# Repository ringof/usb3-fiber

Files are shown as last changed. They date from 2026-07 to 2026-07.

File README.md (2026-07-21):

# USB3-over-Fiber Link

USB3 SuperSpeed carried over an optical fiber link, using a **DS100BR111**
redriver into a **10GbE SR SFP+** optical module. A single symmetric PCB serves
both ends of the link — host-side and remote-side roles are selected by jumpers.
The **MCP2221A** provides the SFP+ management (I²C) interface and GPIO for
`TX_DISABLE` / `RX_LOS`. **No microcontroller, no firmware, no EEPROM.**

Built as the remote front-end for an SDR receiver: put the ADC at the antenna
and stream USB3 back to the shack over fiber.

## How it works

```
USB3-A connector        ┌───────────────┐        SFP+ cage
(SuperSpeed pairs) ─────►│  DS100BR111   │◄─────► (optical module) ──► fiber
                        │ (pin-strapped, │
                        │   3.3V)        │
                         └───────────────┘
                                │ SDA/SCL
                          ┌───────────┐
                          │ MCP2221A  │── USB micro-B ── laptop (SFP+ mgmt)
                          └───────────┘
```

Each fiber link needs **two identical boards** — one at the antenna, one at the
shack — with jumpers `JP1`/`JP2` selecting the role. The USB3 path is fully
symmetric: the DS100BR111 is bidirectional and the SFP+ module handles both TX
and RX in one cage.

## Central hypothesis

This prototype exists to test one thing:

> A 10GbE SR SFP+ optical module will transport USB3 SuperSpeed signalling
> intact — LFPS bursts, link training, electrical-idle transitions,
> spread-spectrum clocking, and receiver detection — without modifying the
> module or the USB3 endpoints.

It has been done in the amateur-radio and USB-extension communities, but it is
guaranteed by no specification. See
[`docs/USB3_Fiber_Link_Minimal_Circuit.md`](docs/USB3_Fiber_Link_Minimal_Circuit.md)
for the architecture, channel assignment, and the failure modes this board is
built to probe.

## Repository layout

| Path | Contents |
|---|---|
| `usb3_fiber.kicad_pro/.kicad_sch/.kicad_pcb` | The design. |
| `usb3_fiber.kicad_dru` | Custom high-speed design rules (length/skew/coupling/isolation/via-count). |
| `fp-lib-table` / `sym-lib-table` | Project-local library tables (`${KIPRJMOD}`). |
| `library/` | Symbols (`usb3_fiber.kicad_sym`), footprints (`.pretty/`), 3D models (`3dmodels/`). |
| `datasheets/` | Component datasheets. |
| `docs/` | Design intent, fab spec, turnkey/CI pipeline, release strategy, and the repo migration plan. |

## Requirements

- **KiCad 10.0** (latest stable 10.0.4) — the project baseline.

## Building the manufacturing outputs

From the repo root, with `kicad-cli` (KiCad 10):

```sh
kicad-cli sch erc   usb3_fiber.kicad_sch --output erc.rpt
kicad-cli pcb drc   usb3_fiber.kicad_pcb --output drc.rpt   # honors .kicad_dru
kicad-cli sch export pdf     usb3_fiber.kicad_sch --output schematic.pdf
kicad-cli sch export bom     usb3_fiber.kicad_sch --output bom.csv
kicad-cli pcb export gerbers usb3_fiber.kicad_pcb --output gerbers/
kicad-cli pcb export drill   usb3_fiber.kicad_pcb --output gerbers/
kicad-cli pcb export pos     usb3_fiber.kicad_pcb --output cpl.csv
kicad-cli pcb export step    usb3_fiber.kicad_pcb --output usb3_fiber.step
```

## Fabrication

4-layer FR4, ENIG, controlled impedance (100 Ω differential on the high-speed
pairs), targeting **JLCPCB's standard 4-layer process**. Full stackup,
impedance, and drill/feature constraints are in
[`docs/fab_specification.txt`](docs/fab_specification.txt).

## Downloads

Latest release (see [all releases](../../releases)):

- 📄 **[Schematic (PDF)](https://github.com/ringof/usb3-fiber/releases/latest/download/usb3_fiber-schematic.pdf)**
- 🧩 **[Assembly drawing (PDF)](https://github.com/ringof/usb3-fiber/releases/latest/download/usb3_fiber-assembly.pdf)** — top + bottom component placement
- 📐 **[Fabrication drawing (PDF)](https://github.com/ringof/usb3-fiber/releases/latest/download/usb3_fiber-fabrication-drawing.pdf)** — overview/spec, per-layer, and drill maps
- 🛠 **[Gerbers — JLCPCB-ready (zip)](https://github.com/ringof/usb3-fiber/releases/latest/download/usb3_fiber-gerbers.zip)**
- 📦 **[Full fabrication + design package (zip)](https://github.com/ringof/usb3-fiber/releases/latest/download/usb3_fiber-fabrication.zip)** — Gerbers, drill, BOM, CPL, schematic PDF, assembly + fabrication drawings, STEP

Packages are built and version-stamped by CI. Versioning is semantic
(`vMAJOR.MINOR`): `dev` publishes `v0.x` pre-releases, and promotion to `main`
cuts production releases (`v1.0`, then `v2.0`, …). The version and git hash are
stamped into the title block and bottom silkscreen at build time, and named in
each release's title/tag. The download links above resolve to the newest
**production** release; during the pre-1.0 phase (only `v0.x` pre-releases so
far), grab the assets from the specific pre-release on the
[Releases page](../../releases). See
[`docs/RELEASE_STRATEGY.md`](docs/RELEASE_STRATEGY.md) for how versions and
releases work (a new version is cut only when the design changes).

## Status

Prototype. This is an unproven design intended to validate the central
hypothesis above. The current revision is whatever the latest
[release](../../releases) is — it's stamped into the board, not hardcoded here.

## License

[CERN-OHL-P v2](LICENSE) (CERN Open Hardware Licence Version 2 – Permissive,
SPDX `CERN-OHL-P-2.0`).

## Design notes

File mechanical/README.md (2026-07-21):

# Mechanical — enclosure & PCB end plates

The mechanical package for the USB3-over-Fiber link: the enclosure model and the
end-plate boards. It lives in **this repo, not a separate one** — see below.

> **Status: scaffold.** This README fixes the convention. Drop the enclosure STEP
> and the end-plate KiCad projects in here as they are created.

## Layout

```
mechanical/
  enclosure.step          # the case model — the EE↔ME interface artifact
  endplate-*/             # standalone KiCad projects, one per panel
```

Each end plate is its **own** self-contained KiCad project (its own
`fp-lib-table` / `sym-lib-table`); the root `usb3_fiber` board is untouched. The
end plates are **non-functional PCBs** — Edge.Cuts, connector cutouts, mounting
holes, and silkscreen (labels + logos) — fabricated in place of the blank panels
a stock enclosure ships with.

Because the board is symmetric — one design serves both the antenna-side and
shack-side ends of the link — a single set of end plates fits both units.

## Why in this repo, not a separate one

The end plates are **mechanically coupled** to the main board: their cutouts have
to track the board's connector positions — the USB3-A connector (`J3`/`J4`), the
SFP+ cage opening (`J1`), and the USB micro-B management port. Keeping them here
means a connector move and its matching cutout move land as **one atomic,
reviewed commit**, and they version and travel together. A separate repo would
split that into two places to keep in sync by hand — exactly the drift we're
avoiding.

## Versioning — deliberately separate from the board

A change under `mechanical/` **does not cut a board release.** The `dev-release`
/ `main-release` version lanes are scoped to the **root board's** files only —
they list `usb3_fiber.kicad_{sch,pcb,pro,dru}`, `library/`, and the lib-tables
explicitly rather than globbing `*.kicad_pcb` (which, as a git pathspec, would
match `mechanical/**` at any depth and false-trigger a board release). So an
end-plate silkscreen tweak never bumps the board's `vX.Y`. That scoping is
already in place — see #38.

The end plates are simple; build their fab outputs **on demand** for now, e.g.:

```sh
kicad-cli pcb export gerbers mechanical/endplate-front/endplate-front.kicad_pcb -o mechanical/endplate-front/gerbers/
kicad-cli pcb export drill   mechanical/endplate-front/endplate-front.kicad_pcb -o mechanical/endplate-front/gerbers/
```

A dedicated end-plate CI lane is a possible later addition, not a requirement.

## The board STEP is the interface

Mechanical design works from the board's exported **STEP** — board outline,
thickness, connector positions, component heights, and mounting holes.
`scripts/build_release.sh` already exports `usb3_fiber.step` (bundled inside the
`usb3_fiber-fabrication.zip` release asset). Publishing it as a **standalone
release asset** — so the case design can always pull the current board without
unzipping the fab package — is a small follow-up on the release jobs, and ties
into the 3D-model-completeness work. Until then, grab the STEP from inside the
latest release's fabrication zip, or regenerate it with:

```sh
kicad-cli pcb export step usb3_fiber.kicad_pcb -o usb3_fiber.step
```

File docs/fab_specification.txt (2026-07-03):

USB3 FIBER LINK - PCB FABRICATION SPECIFICATION
================================================

1. GENERAL REQUIREMENTS
   Board Name:         USB3 Fiber Link
   Layers:             4 (TOP / GND / PWR / BOTTOM)
   Material:           FR4, Standard Tg (150-160C)
   Finished Thickness: 62 mil (1.575mm) +/- 10%
   Surface Finish:     ENIG (1u" min gold thickness)
   Solder Mask:        Green, both sides (LPI)
   Silkscreen:         White, both sides
   IPC Class:          2 (Standard)
   UL Marking:         Not required

2. STACKUP
   Layer          Type       Thickness    Copper Weight
   -----          ----       ---------    -------------
   F.Cu           Signal     0.035mm      1 oz
   Prepreg        7628       0.21mm       Er=4.5, Df=0.02
   In1.Cu         GND Plane  0.0175mm     0.5 oz
   Core           FR4        1.03mm       Er=4.5, Df=0.02
   In2.Cu         PWR Plane  0.0175mm     0.5 oz
   Prepreg        7628       0.21mm       Er=4.5, Df=0.02
   B.Cu           Signal     0.035mm      1 oz

   Note: Exact prepreg/core thicknesses subject to fab stackup
   optimization for impedance targets below.

3. CONTROLLED IMPEDANCE
   Net Class       Type           Target     Tolerance
   ---------       ----           ------     ---------
   USB3_SS         Differential   100 ohm    +/- 10%
   USB3_SS         Single-ended   50 ohm     +/- 5 ohm
   SFP_SS          Differential   100 ohm    +/- 10%
   SFP_SS          Single-ended   50 ohm     +/- 5 ohm
   USB2            Differential   90 ohm     +/- 10%
   USB2            Single-ended   45 ohm     +/- 5 ohm

   Impedance-controlled traces are on F.Cu and B.Cu layers
   referenced to In1.Cu (GND) plane.

4. MINIMUM DESIGN FEATURES
   Parameter                    Value
   ---------                    -----
   Minimum track width          0.10mm (4 mil)
   Minimum track spacing        0.10mm (4 mil)
   Minimum via drill            0.30mm
   Minimum via pad diameter     0.50mm
   Minimum annular ring         0.10mm
   Minimum hole-to-hole         0.25mm
   Minimum copper-to-edge       0.50mm
   Minimum solder mask bridge   0.10mm (green, 1oz)
   Minimum mask-to-trace        0.09mm
   Minimum silkscreen width     0.153mm (6 mil)
   Minimum silkscreen height    1.0mm (40 mil)

5. DRILL REQUIREMENTS
   Plated through-hole tolerance:    +0.13 / -0.08mm
   Non-plated hole tolerance:        +/- 0.20mm
   Minimum plated slot width:        0.50mm
   Minimum non-plated slot width:    1.00mm
   No blind or buried vias required.

6. VIA TREATMENT
   All vias to be filled with soldermask (opaque finish).
   Filled vias must not have soldermask openings on either side.
   Maximum via diameter for plugging: 0.50mm.

7. DESIGN RULE CONSTRAINTS (enforced in layout)
   Net Class       Max Length   Diff Pair Skew   Track/Gap       Max Uncoupled
   ---------       ----------   --------------   ---------       -------------
   USB3_SS         25mm         0.1mm            0.2mm / 0.2mm   2mm
   SFP_SS          15mm         0.1mm            0.2mm / 0.2mm   2mm
   USB2            50mm         0.5mm            0.2mm / 0.15mm  5mm
   Power           --           --               0.5mm / 0.2mm   --
   Default         --           --               0.2mm / 0.2mm   --

   Additional high-speed constraints:
   - USB3 TX/RX pair-to-pair clearance:   0.5mm minimum
   - SFP TD/RD pair-to-pair clearance:    0.5mm minimum
   - USB3 to SFP inter-class clearance:   0.5mm minimum
   - USB3_SS max via count per net:        2
   - SFP_SS max via count per net:         2

8. NOTES
   a. All dimensions in millimeters unless otherwise noted.
   b. Panelization per fabricator requirements.
   c. Board outline defined in Edge.Cuts layer of Gerber files.
   d. Fiducials provided (4x, 1mm Cu with 2mm mask opening).
   e. Mounting holes: 4x M3 (3.2mm), non-plated.
   f. Fab to verify trace widths against actual stackup using
      impedance calculator and adjust if necessary.
   g. Target fabricator: JLCPCB (4-layer standard process).

9. DELIVERABLES REQUIRED FROM FABRICATOR
   a. Impedance test coupon results
   b. Cross-section report (if controlled impedance ordered)
   c. Final stackup confirmation before production

REVISION HISTORY
   Rev    Date          Description
   ---    ----------    -----------
   A      2026-03-13    Initial release

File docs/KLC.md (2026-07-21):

# KLC Compliance & Accepted Deviations

How this project relates to the **KiCad Library Convention (KLC)**, and the
places where we **intentionally deviate** from it.

KLC is checked in dev CI by `scripts/klc_check.sh` (kicad-library-utils over
`library/usb3_fiber.kicad_sym` and `library/usb3_fiber.pretty/`). It is
**warning-level only — it never gates a build** (see `docs/REPO_MIGRATION_PLAN.md`
Phase 5). The report is published to the `ci-docs` branch (`klc.txt`) and echoed
into the CI job summary.

The goal is **not** zero violations. KLC is written for the *official* KiCad
libraries; this is a **self-contained project library** with turnkey-assembly
requirements. A handful of KLC rules conflict with those requirements, and
"fixing" them would damage the design or the manufacturing pipeline. Those cases
are listed here as accepted deviations; everything else is remediated (tracked
in #36 and batch issues #32–#35).

## Accepted deviations

### 1. Custom BOM / part-spec fields — violates **S6.2** ("unexpected property")

Symbols carry non-standard fields that KLC flags as unexpected:

- `MANUFACTURER`, `Manufacturer Part Number` (MPN), `Vendor` / `Vendor Part
  Number` (LCSC), `PARTREV`
- Value-class attributes on the generic spec symbols: `Voltage`, `Tolerance`,
  `Temperature Coefficient`, `Impedance`, `DC Resistance`, `Max Current`, …

**Why kept:** these drive the **turnkey outputs** — the LCSC/JLCPCB BOM and the
rotation-corrected CPL read the `LCSC` / MPN / manufacturer fields (see
`usb3_fiber.kibot.yaml` and `docs/TURNKEY.md`). Deleting them to satisfy KLC
would break assembly ordering. **We keep them and accept the S6.2 flag.**

### 2. Project-local 3D-model layout — **F9.3 excluded** in the checker

Our 3D models are **committed to the repo** at `library/3dmodels/*.step` and
referenced as `${KIPRJMOD}/library/3dmodels/<model>.step`, so the library is
**self-contained** — models travel with the repo and resolve in CI with no
system-wide KiCad install.

KLC's **F9.3** is *structurally unsatisfiable* for this layout, by design of the
rule (verified in `rules_footprint/F9_3.py`): it only accepts the path prefix
`${KICAD10_3DMODEL_DIR}/` (the *global install* dir) and requires the model
directory to be exactly `<libname>.3dshapes`. With `${KIPRJMOD}` the prefix is
never stripped, so the directory check can never pass — conforming would mean
abandoning self-containment (installing models globally). It is therefore
**excluded** in `scripts/klc_check.sh` (`--exclude F9.3`). 3D-model *presence /
completeness* is covered separately by the planned 3D-completeness gate, so no
real coverage is lost.

(**F9.1** — footprint metadata — is *not* excluded: descriptions, keywords, and
datasheet URLs are filled in, and F9.1 is fully cleared. The unused
`QFP50P900X900X160-48N` footprint and the unused `USB2517I` part
(`QFN64_USB2517I` footprint + symbol + 3D model) were removed from the library.)

### 3. Generic value symbols have no datasheet — part of **S6.2**

`C_Spec`, `R_Spec`, `FB_Spec` are **generic value symbols** (a capacitor /
resistor / ferrite placeholder whose value is set per-instance), not specific
orderable parts, so they have no single datasheet. Leaving `Datasheet` empty on
these is intentional. **Accepted.** (Orderable parts do carry a datasheet.)

## What we DO remediate

Everything not listed above is fixed on the `dev-klc-compliance` branch, in
batches:

- **#32** — metadata & library linkage: footprint-filter formatting/escaping,
  missing/surplus filters, symbol keywords, footprint descriptions, and adding
  datasheets to orderable parts.
- **#33** — silkscreen, courtyard, and fabrication-layer graphics.
- **#34** — 3D-model requirements (path standardization per deviation 2, plus
  offset/rotation).
- **#35** — pin & pad conventions (per-part, against datasheets).

## Baseline

Post KiCad-10 library migration: **231 violations** (65 symbol + 166 footprint).
The accepted deviations above account for a portion that will remain in the
report by design; the remainder is the remediation target.

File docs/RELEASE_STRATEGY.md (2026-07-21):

# Release Strategy

How `usb3-fiber` versions the design, builds fabrication packages, and publishes
releases. Implemented by `.github/workflows/dev-release.yml` and
`main-release.yml` (with `dev-checks.yml` for pre-merge validation), sharing a
single versioning policy in `scripts/next_version.sh`.

## Branches & CI

Two-tier flow: **feature → `dev` → `main`**.

- **`dev-*`** feature branches are where work happens. They merge (squash) into
  **`dev`**, the permanent integration branch.
- **`dev`** collects vetted work. Each merge cuts a **pre-release** (see below).
  When the design is ready to spin, `dev` merges (squash) into **`main`**.
- **`main`** is the release branch. A merge here promotes the design to a
  **production revision**.
- Both `dev` and `main` are protected (PR required); `main` is the stricter
  release gate.

CI:

- **`dev-checks`** runs on `dev-*` pushes and on **PRs into `dev` and `main`**:
  ERC, DRC, BOM completeness, and schematic + assembly drawings as artifacts. So
  the same checks gate both feature→dev and dev→main.
- **`dev-release`** runs on every merge to `dev` and publishes/refreshes the
  **pre-release** for that iteration.
- **`main-release`** runs on every merge to `main` (and can be dispatched
  manually) and publishes **production revisions** and their packages.

## Versioning

Semantic `MAJOR.MINOR`. Think of it as **`main` = production board spins;
`dev` = the iterations toward the next spin.**

**`main` advances to the next whole `.0`; `dev` does the minor increments** in
between. `dev`'s major line simply follows whatever `main` last shipped.

| Event | Version |
|---|---|
| `dev` merge, pre-1.0 | `0.1 → 0.2 → 0.3 …` (minor++) |
| **first `dev → main`** | **`1.0`** |
| `dev` merge, post-1.0 | `1.1 → 1.2 → 1.3 …` (minor++ in the 1.x line) |
| **next `dev → main`** | **`2.0`** |
| `dev` merge, post-2.0 | `2.1 → 2.2 …` |
| **next `dev → main`** | **`3.0`** |

- **`main` release** = `<latest main major + 1>.0`; first-ever → `1.0`. Every
  production release is a whole major — no auto-minor, and no manual major
  decision needed. Published as a normal (non-prerelease) Release so it lands as
  "Latest".
- **`dev` pre-release** = minor increment within the **current major line**,
  whose major follows the latest `main` release (`0` while pre-1.0). The first
  `dev` pre-release after a `main` `X.0` starts at `X.1`; the very first
  pre-release while pre-1.0 uses the seed (`0.1`). Published with `--prerelease`
  so it never claims "Latest".

The "back it into dev" step is **automatic**: `dev-release` reads `main`'s latest
major through the shared script, so the first pre-release after `main` ships
`1.0` computes as `1.1` on its own — no manual back-merge of a version number.

**GitHub Releases are the source of truth** for the version — no number lives in
the design files. Tags are `v<MAJOR>.<MINOR>`; the title matches (pre-releases
add a ` (pre-release)` suffix). The policy is implemented **once** in
`scripts/next_version.sh` (unit-tested offline by `scripts/test_next_version.sh`)
and called by both lanes, so `dev` and `main` can't drift apart.

> **Legacy tags:** the earlier alpha releases (`revA`/`revB`/`revC`) predate this
> scheme. Both workflows scope their release scan to `v<MAJOR>.<MINOR>` tags, so
> those alpha tags are simply ignored by the version math.

### Pre-releases (dev lane)

`dev-release` runs on every merge to `dev` and publishes a `--prerelease`:

- Computes the next `dev` version via `scripts/next_version.sh dev 0.1` and
  publishes when a design file changed since the last release (of any kind);
  docs/CI/script-only merges are a no-op.
- **First run seeds the line** at `v0.1` from the design at `dev` HEAD —
  automated, no manual tag.
- **Does not retire at 1.0.** After `main` ships `1.0`, `dev` continues in the
  `1.x` line (`1.1`, `1.2`, …) building toward the next `main` (`2.0`); after
  `2.0` it runs `2.x`; and so on.

Both lanes accept the same manual `version` override / `dry_run` inputs.

## When is a new revision cut?

Each lane publishes **only when a design file changed** since its base release;
docs/CI/script-only merges are a **no-op** — they run the workflow, determine
nothing changed, and stop without building or publishing.

- **`dev-release`** compares against the **most recent release of any kind**.
- **`main-release`** compares against the **most recent production
  (non-prerelease) release** — a `dev` pre-release never gates a production spin.
  The **first** production release always publishes `v1.0` (it is the promotion
  of the current design to production, not a diff).

**Design files** (a change to any of these triggers an uprev):

- `usb3_fiber.kicad_sch`, `usb3_fiber.kicad_pcb`, `usb3_fiber.kicad_pro`,
  `usb3_fiber.kicad_dru`
- `library/**` (symbols, footprints, and STEP models), `fp-lib-table`,
  `sym-lib-table`

The root board files are listed **explicitly** in the workflows (not as
`*.kicad_*` globs, which as git pathspecs match at any depth and would let a
future sibling KiCad project under `mechanical/` false-trigger a board release).

**Not design files** (never trigger an uprev): `README.md`, `docs/**`,
`.github/**`, `scripts/**`, and `*.kicad_prl` (editor/UI state).

The comparison is made against **the last release's commit**, not just the
merge's own diff — so a design edit that landed in an earlier (unpublished)
commit is still caught, and a later docs-only merge cannot mask it.

## Provenance (`${REVISION}` and `${GIT_HASH}`)

Both are **injected at build time** (`scripts/inject_provenance.py`) into the
project text variables and rendered into the schematic/PCB **title block** and
the **bottom silkscreen**. Nothing is committed back to the design files — the
defaults committed in `*.kicad_pro` (`DEV` / `local`) are only placeholders for
local opens.

- `${REVISION}` — the version being published (e.g. `0.3`, `1.0`).
- `${GIT_HASH}` — **the last commit that touched a design file**, not `HEAD`.

Stamping the *design* commit (rather than the build's `HEAD`) keeps the mark
truthful and stable: a docs-only commit never changes it, and the same physical
design never ends up stamped with two different hashes.

## Release assets

Each release attaches five **stable-named** assets (no version/hash in the
filename), so `…/releases/latest/download/<name>` links stay valid across
production revisions:

| Asset | Contents |
|---|---|
| `usb3_fiber-schematic.pdf` | Schematic (direct download, no unzip) |
| `usb3_fiber-assembly.pdf` | Assembly drawing (top + bottom, framed) |
| `usb3_fiber-fabrication-drawing.pdf` | Fabrication drawing / dimensions |
| `usb3_fiber-gerbers.zip` | Gerbers + drill (JLCPCB-ready) |
| `usb3_fiber-fabrication.zip` | Full package: gerbers, drill, BOM, CPL, PDFs, STEP |

The version and git hash live inside the files and in the release title/tag, not
in the filenames.

> `…/releases/latest/download/<name>` resolves to the latest **production**
> release. During the pre-1.0 phase (only `v0.x` pre-releases exist), link people
> to the specific pre-release's page instead — pre-releases never claim "Latest".

## Manual releases

Both workflows listen to a manual `workflow_dispatch` in addition to their push
trigger — driven entirely by inputs, no YAML editing.

- **`version`** — force a specific number (`main`: e.g. `2.0`; `dev`: e.g. `0.7`).
  Blank = automatic. Re-publishing an existing version is idempotent: the job
  refreshes that release's assets (`gh release upload --clobber`) instead of
  failing, so it doubles as the "re-publish / fix a release" button.
- **`dry_run: true`** — build the full turnkey package and upload it as **run
  artifacts** (`release-package`) **without** publishing. Forces a build even
  when no design file changed, so the pipeline (e.g. a KiBot config change) can
  be validated before committing to a real release. Provenance is still injected,
  so the artifacts carry the version they *would* be published under.

## Edge cases

- **First pre-release:** no prior release → seed `v0.1`.
- **First production release:** no prior production release → `v1.0` (always
  publishes — it is the promotion of the current design to production).
- **`dev` after a `main` release:** `dev`'s major follows the latest `main`, so
  the first pre-release after `1.0` is `1.1` (not `0.x`, not `2.0`); pre-releases
  are `--prerelease` so they never advance the `main` number.
- **Doc-only merge after a design change is already released:** no-op on either
  lane — the released design is unchanged.
- **`main` merge with no design change since the last production release:** no-op
  — a production major is never spent on nothing.

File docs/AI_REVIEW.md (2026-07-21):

# Using AI review on this project

This project is developed largely with AI assistance (Claude and similar), and
AI-assisted *review* of the design is welcome — it can be genuinely useful. It
can also confidently invent problems that don't exist and waste real review
cycles. This file exists so that anyone pointing an AI at this board does it the
way that helps, not the way that misleads.

Read this before pasting the design into any AI tool and reporting what it says.
It is the same "Evidence before claims" rule already in `CLAUDE.md`, spelled out
for AI output specifically.

## The core rule: a finding is a lead, never a verdict

An AI model will state things about this design with total confidence, including
things that are wrong. Its sense of the netlist — what is *actually* wired to
what — is weak unless it has been carefully grounded first (see below). It also
tends to tell you what sounds alarming, or what flatters the question you asked.

So: treat every AI finding as a **lead to check against the real design**, not as
a result. Nothing an AI says gets filed as an issue, and nothing gets acted on,
until it has been verified against the current schematic/PCB and the closed
issues. If you can't personally verify a finding, say so when you report it —
"the model flagged X, I haven't confirmed it" — don't pass it on as fact.

This is not hypothetical. On the sibling board `ringof/taprx888`, an AI reviewer
once "conclusively" reported that a controller's power/ground was inverted — it
wasn't. The model was reasoning without the reference material. That near-miss is
why both repos carry this document.

## Ground the model before you trust a single word

Before you ask an AI anything design-level about this board, give it, in roughly
this order:

1. **The datasheets for the actual parts on this board:**
   - **DS100BR111** — USB3 SuperSpeed redriver (`U2`). Local copy:
     `datasheets/ds100br111.pdf`. This is the heart of the signal path; its
     receiver/driver equalization straps and I/O conventions are where most
     real questions live.
   - **MCP2221A** — USB-to-I²C/UART bridge (`U1`) that provides the SFP+
     management interface. (No microcontroller and no firmware are involved —
     if a model starts reasoning about firmware, it has lost the plot; see
     `docs/USB3_Fiber_Link_Minimal_Circuit.md`.)
   - **The SFP+ module + cage** (`J1`/`J2`) — the relevant MSA specs (SFF-8431
     for the electrical/host side, SFF-8419/SFF-8074 for the connector) define
     the management I²C, LOS/TX-fault sidebands, and supply/decoupling rules.
     See `datasheets/hsio_cn_expressport_sfp.pdf` and the module datasheet
     (`datasheets/Ux76-A20-x00xx.pdf`).
   - **LD1086-3.3** (`U4`) — the 3.3 V LDO. Local family datasheet:
     `datasheets/LD1117.pdf`.
   - Note: the `datasheets/` folder also contains parts (e.g. FT232H, USB2517)
     that are **not** on the current BOM — do not let a model "review" against a
     part this board doesn't use. The authoritative part list is the schematic
     and the BOM the CI check exports, not the datasheet folder.
2. **The design intent** — `docs/USB3_Fiber_Link_Minimal_Circuit.md` (the
   architecture and the central hypothesis) and `docs/fab_specification.txt`
   (stackup, impedance, fab constraints). Much of what an ungrounded model
   "finds" about layer stackup or impedance is answered directly here.
3. **The current design** — the `usb3_fiber.kicad_sch` / `usb3_fiber.kicad_pcb`
   from the repo (or, better, an exported netlist/PDF), not a description of it.
4. **The closed issues** —
   <https://github.com/ringof/usb3-fiber/issues?q=is%3Aissue+state%3Aclosed>.
   Closed issues are already-decided items. An ungrounded model will
   "rediscover" them as new problems. Always check a finding against the closed
   list — and the open list — first.

An AI that hasn't been given these is not reviewing the board — it's guessing
about a board.

## How to actually run a useful review (the method)

1. **Prime it** with the material above — datasheets, design intent, and the
   schematic/netlist — before asking for findings.
2. **Expect the first pass to be poor, and challenge it.** Don't accept the
   opening answer; push back, ask it to trace the actual net, ask how it knows.
3. **Distill.** Its raw output is feedstock, not conclusions. Pull out the
   claims worth checking, verify each against the real design and the closed
   issues, and only then do you have something worth filing.
4. **File verified findings as normal issues** — one item each, "clear is kind,"
   with the datasheet / app-note / spec reference that backs it, in the house
   style already used across this tracker (see the existing DRC/ERC/KLC issues).
   File them as *your* findings that you've checked — not as "the AI said."

## What AI is genuinely good for here

Not all warnings — it's real help when grounded: sanity-checking a pinout
against a datasheet you've *also* handed it, cross-referencing an SFF/MSA or
DS100BR111 requirement, drafting issue text, explaining an unfamiliar corner of
the SFP+ management interface, or generating BOM/CI/tooling scripts (much of this
repo's CI was built exactly that way). The pattern that works is **"help me check
a specific thing I can then verify,"** not "tell me what's wrong with this
board." The difference between useful and misleading is entirely in the grounding
you give it and the checking you do after. Do both, or don't report the output.

## Related

- `CLAUDE.md` — the working agreement, including "Evidence before claims."
- `docs/USB3_Fiber_Link_Minimal_Circuit.md` — architecture and design intent.
- `ringof/taprx888:docs/AI_REVIEW.md` — the sibling board's version of this
  guidance, where the near-miss above originated.

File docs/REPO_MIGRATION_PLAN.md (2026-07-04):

# USB3-Fiber KiCad Repository Migration Plan

Porting the repository-infrastructure work proven out on
[`ringof/taprx888`](https://github.com/ringof/taprx888) to this project, adapted
to the requirements agreed for this repo.

> **Scope note:** This plan covers *repository, layout, CI, release, provenance,
> and library/rule-hygiene infrastructure* — the automation and quality layer
> around the KiCad design. It deliberately excludes the AI-authored
> schematic-review documents that lived at the top of the taprx888 repo.

---

## 1. What the taprx888 effort delivered (infra layer)

Setting the review write-ups aside, the reusable pattern was: a headless
`kicad-cli` CI pipeline producing checks and fabrication outputs; `GIT_HASH`
provenance stamped into the design; ERC/DRC/library findings filed as tracked
issues; a README with download links; fabrication outputs published as releases;
and a LICENSE.

## 2. Current state of this repo

- ✅ Migrated to **KiCad 10.0** (`version 20260206`; latest stable 10.0.4),
  4-layer, targeting JLCPCB.
- ✅ **Flattened** to the repo root (out of the former `usb3_fiber/` subdir); an
  orphan `.history` gitlink accidentally committed during the migration was
  removed and `.gitignore`d.
- ✅ `LICENSE` (CERN-OHL-P v2) and root `README.md` added.
- ✅ **`main` protected** (see the policy below) and **squash-only merges**
  configured.
- ✅ **Dev CI** (`dev-checks.yml`): ERC/DRC/BOM + schematic/assembly drawings,
  bring-up mode (`ENFORCE=false`).
- ✅ **Main-release CI** (`main-release.yml`): computes the alpha revision from
  the latest Release, injects `REVISION`/`GIT_HASH`, builds the full turnkey
  package, and publishes a GitHub Release with stable-named assets (schematic,
  assembly + fabrication drawings, gerbers, full package).
- ✅ **Framed documentation pipeline**: schematic / assembly / fabrication PDFs
  are rendered natively by `scripts/gen_docs.sh` (kicad-cli) — see
  `docs/TURNKEY.md`. KiBot is retained only for turnkey data (gerbers, drill,
  CPL, LCSC BOM, iBOM, STEP, renders). The CI base image is pinned
  (`ghcr.io/ringof/kicad-ci`, kicad10_auto + PyMuPDF).
- ✅ **Provenance (title block)**: `${REVISION}` / `${GIT_HASH}` text variables
  defined and referenced in the schematic + PCB title blocks; injected at build
  time by the release CI.
- **Strong** design docs already committed: `docs/fab_specification.txt` and
  `docs/USB3_Fiber_Link_Minimal_Circuit.md`, plus a custom
  `usb3_fiber.kicad_dru` with high-speed rules.
- **Still open:** the **bottom-silkscreen** provenance text (needs placement in
  KiCad — see Phase 2 note), flipping `ENFORCE=true` + adding required status
  checks, the **3D-model-completeness gate** on `main`, and the **KLC + fab-rule
  audit** (Phase 5). Assembly fit-extent refinement tracked in issue #29.
- Known static finding: `In1.Cu`/`In2.Cu` are typed `signal` in the PCB though
  the fab spec defines them as GND/PWR planes (same class as taprx888 #12).

## 3. Agreed requirements

These decisions drive the plan below:

1. **Repo layout — flatten.** The KiCad project lives at the **repo root**, not
   nested in a duplicate `usb3_fiber/` folder. Move via history-preserving
   `git mv`. Safe: all internal paths use `${KIPRJMOD}` / `${KICAD8_3DMODEL_DIR}`
   (verified — no hardcoded `usb3_fiber/` references).
2. **Branch model.** Two-tier flow: **feature → `dev` → `main`**. `dev-*` feature
   branches merge (squash) into the permanent **`dev`** integration branch; `dev`
   merges (squash) into **`main`** only when cutting a release. Both `dev` and
   `main` are protected via rulesets (Settings → Rules → Rulesets): require a
   pull request (**0 required approvals**), **restrict deletions**, **block force
   pushes**, with a **Repository admin bypass**. `main` is the stricter release
   gate. Required status checks are intentionally **off for now** — the
   ERC/DRC/BOM gates get added to both rulesets once dev CI is trusted. Merges
   are **squash-only** (Settings → General → Pull Requests), keeping both
   branches linear. `dev-checks` runs on PRs into **both** `dev` and `main`.
3. **Dev CI** (on `dev-*`): ERC, DRC, BOM check, and generation of schematic PDF
   + assembly-drawing outputs as build artifacts.
4. **Main CI** (on `main`): produce the full design/fabrication package and
   **uprev the revision** stamped on the silkscreen.
5. **Revision scheme.** **Alpha** (Rev A → B → C), **injected at build time**
   (same mechanism as `GIT_HASH`, nothing committed back to `main`).
   **GitHub Releases are the source of truth** for the current revision.
6. **Library audit.** Evaluate **all** local library assets (symbols,
   footprints, 3D models) for compliance with the **KiCad Library Convention
   (KLC)** via `kicad-library-utils`. KLC results are **warning-level only** —
   never a build gate.
7. **Fab/assembly rule baseline.** Adopt **JLCPCB (standard 4-layer process)**
   capabilities as the reference. Set any missing DRC rules and validate
   existing ones against it.
8. **3D-model completeness.** Every **fitted** component must have a working 3D
   model. **Unplaced/DNP** parts are exempt. Enforced as a **gate on the main /
   fab path** (warning on dev).
9. **BOM check.** Every fitted part must have MPN + footprint + value with no
   empty required fields, DNP handled correctly. **Gate.**

**Gate vs. warning summary**

| Check | dev-* | main |
|---|---|---|
| ERC | gate | gate |
| DRC (JLCPCB + custom rules) | gate | gate |
| BOM check | gate | gate |
| 3D-model completeness (fitted parts) | warning | **gate** |
| KLC library compliance | warning | warning |

## 4. Target repository layout (after flatten)

```
/
├── usb3_fiber.kicad_pro / .kicad_sch / .kicad_pcb / .kicad_prl / .kicad_dru
├── fp-lib-table / sym-lib-table
├── library/            (usb3_fiber.kicad_sym, .pretty/, 3dmodels/)
├── datasheets/
├── docs/               (fab_specification.txt, minimal-circuit doc, this plan)
├── README.md
├── LICENSE
└── .github/workflows/  (dev-checks.yml, main-release.yml)
```

## 5. Phased plan

### Phase 0 — Migrate to KiCad 10.0 + baseline capture
- **Migrate the project to KiCad 10.0** first: open in KiCad 10 and re-save so all
  `.kicad_pro/.kicad_sch/.kicad_pcb/.kicad_sym/.kicad_mod` files are rewritten to
  the v10 S-expression format. This is a large, mechanical diff — keep it in its
  own commit, separate from any substantive change, so later diffs stay readable.
- Pin CI to **KiCad 10.0.x** (10.0.4 at time of writing).
- Then run `kicad-cli sch erc` and `kicad-cli pcb drc` (fed `usb3_fiber.kicad_dru`)
  to capture a violation baseline — the reference point for Phase 5 issues.

### Phase 1 — Layout flatten + repo hygiene
- `git mv usb3_fiber/* .` (and dotfiles) to bring the project to the repo root;
  merge `usb3_fiber/docs/` into root `docs/`. Verify project opens and lib
  tables resolve.
- Root `README.md` (description from the minimal-circuit doc, architecture
  summary, download-links section pointing at Releases, build-from-source note).
- `LICENSE` — **CERN-OHL-P v2** (permissive, hardware-native; SPDX
  `CERN-OHL-P-2.0`). Added.
- Extend `.gitignore` for `kicad-cli` output dirs (`fab/`, `gerbers/`, etc.).

### Phase 2 — Provenance (build-time injection)
- Add `${GIT_HASH}` and `${REVISION}` text variables; reference them in the
  schematic title block and the **bottom silkscreen**.
- CI fills both at build time — short SHA for `GIT_HASH`, the computed alpha
  letter for `REVISION`. Nothing is committed back to the design files.

### Phase 3 — Dev CI (`.github/workflows/dev-checks.yml`, on `dev-*`)
- Headless `kicad-cli` in a pinned KiCad 10.0.x container.
- Jobs: **ERC** (gate), **DRC** (gate, incl. custom `.kicad_dru`), **BOM check**
  (gate), **3D-completeness** (warning), **KLC** (warning).
- Generate **schematic PDF** and **assembly drawings** (fab/assembly PDF + CPL);
  upload as build artifacts.

### Phase 4 — Main CI + release (`.github/workflows/main-release.yml`, on `main`)
- All dev checks, plus **3D-completeness as a gate**.
- Compute next alpha revision by reading the **latest GitHub Release**; inject
  `REVISION` + `GIT_HASH`.
- Export the full package: Gerbers, drill, BOM, CPL, schematic PDF, assembly
  drawings, and STEP. Zip and **publish as a new GitHub Release** under the new
  rev (e.g. `revB`).

### Phase 5 — Rule + library hardening
- **Fab rules (JLCPCB standard 4-layer):** reconcile `.kicad_pro`
  `board_design_settings` and `usb3_fiber.kicad_dru` against JLCPCB's published
  capabilities; enable checks found disabled in the taprx888 pattern (courtyard,
  dielectric/impedance); fix the `In1.Cu`/`In2.Cu` `signal`→plane typing.
- **KLC audit:** run `kicad-library-utils` klc-check over the symbol lib,
  `.pretty` footprints, and 3D models; wire it into CI as a warning-level report.
- File remaining Phase-0 and audit findings as tracked GitHub issues.

### Phase 6 — First tagged release
- With CI green on `main`, cut the first release (**Rev A**, matching the fab
  spec revision history) — the first provenance-stamped, reproducible package.

## 6. Suggested execution order

`Phase 0` → `Phase 1` → `Phase 2` → `Phase 3` → `Phase 4` → `Phase 5` →
`Phase 6`.

Phases 1–2 touch layout + provenance and are the lowest-risk first PR. Phases
3–4 stand up the two-tier CI. Phase 5 is the rule/library hardening pass. Phase
6 is the payoff: a reproducible, revision-stamped fabrication package driven off
GitHub Releases.

## 7. Open items

*(Resolved: LICENSE = CERN-OHL-P v2. KiCad version = 10.0, migrated up front in
Phase 0.)*

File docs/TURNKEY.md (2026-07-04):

# Turnkey Assembly & KiBot Pipeline

How the CI produces **overseas-turnkey-ready** manufacturing outputs, via
[KiBot](https://github.com/INTI-CMNB/KiBot). Generic where possible, **JLCPCB-
profiled** where it matters.

## What turnkey needs (and where we were weak)

| Input | Status before | Now |
|---|---|---|
| Gerbers + drill | ✅ ok | JLCPCB gerber/drill profile |
| **Position / CPL** | ⚠️ geometrically right but **not rotation-corrected** | KiBot `rotated` variant (`_rot_footprint`) → JLCPCB-correct rotations |
| **BOM with LCSC** | ⚠️ generic, ~half of parts lack LCSC | JLCPCB BOM keyed on the `LCSC` field |
| iBOM / 3D render | ✗ | added |

The rotation correction is the big one — without it, an assembly house places
parts turned 90°/180°.

## Design decisions

- **Fab-agnostic base, JLCPCB profile.** One `.kibot.yaml`; the JLCPCB-specific
  outputs live in a `JLCPCB/` group. Other fab houses can get their own group
  later without disturbing this.
- **LCSC is the source of truth for assembly.** Our schematic already carries an
  **`LCSC`** field. KiBot's `only_jlc_parts` filter (LCSC matches `^C\d+`)
  selects what gets assembled; everything else is treated as do-not-place.
- **Rotation corrections** come from KiBot's built-in rotations database via the
  `rotated` variant. Odd footprints can be nudged with a per-part
  `JLCRotOffset` field — no global table to maintain.
- **BOM gate flips to LCSC-required.** The completeness check now fails a fitted
  part that has **no `LCSC`** (was: MPN *or* LCSC). This makes a green build mean
  "actually orderable as turnkey." Expect it to flag parts until the BOM is
  fully populated (issue #14 writ large).
- **PCB gets its own worksheet.** The board points at `usb3_fiber-fab.kicad_wks`
  (the schematic uses `usb3_fiber-sch.kicad_wks`), so the fab/assembly sheet can
  carry documentation-specific zones without disturbing the schematic frame.
  Both start from the same collision-safe title block (`${REVISION}` field +
  `${GIT_HASH}`/`${LICENSE}`/`${DESIGNER}`/`${REPO}` vars), so provenance
  injection stamps them identically.
- **Framed docs come from kicad-cli, not KiBot.** `scripts/gen_docs.sh` renders
  the schematic, assembly, and fabrication PDFs with `kicad-cli`, because KiBot's
  `pcb_print`/`pdf_sch_print` frame renderer left the title-block variables blank
  in our container. `kicad-cli` plots the frame natively, so `${TITLE}` / rev /
  date / designer / licence / repo / commit all fill. KiBot keeps only the
  interactive HTML BOM (kicad-cli has no equivalent) plus the turnkey data.
- **CI never trusts the local sheet setting.** `gen_docs.sh` passes the worksheet
  and provenance **explicitly** (`--drawing-sheet usb3_fiber-{sch,fab}.kicad_wks`
  and `--define-var`), so the rendered frames come from the files on disk
  regardless of the project's `page_layout_descr_file` or `text_variables`. KiCad
  is prone to blanking, embedding (`kicad-embed://`), or rewriting those local
  settings — none of which can affect CI. Keep the worksheets as plain external
  files (no embedding); the overrides depend on them being on disk.
- **Two documentation PDFs, both on the fab worksheet.**
  - `usb3_fiber-assembly.pdf`: **Top** + **Bottom** in one PDF (Fab + Silk + Edge)
    — what a placement operator reads.
  - `usb3_fiber-fabrication-drawing.pdf`: a **notes/stackup** page first, then a
    page **per PCB layer** (copper / silkscreen / mask), then framed **drill
    maps** (PTH + NPTH, vector-composited into the sheet with PyMuPDF).

  `Dwgs.User` / `Cmts.User` / `User.1` ride on the relevant pages, so dimensions,
  notes, and KiCad-placed **stackup / board-characteristics tables** drawn on
  those layers in the board editor render automatically. KiCad has no true
  Draftsman editor — this layer-driven approach is how the documentation gets
  built up. Each page's `${LAYER}` label is injected per page via `--define-var`.

## What KiBot does NOT change (hard constraints)

- **Provenance injection stays.** `scripts/inject_provenance.py` still writes the
  title-block **`rev` field** and the **`GIT_HASH`** text variable *before* KiBot
  runs, so the rendered schematic/board and the custom worksheet keep their
  Rev + commit stamp. KiBot only *generates*; it never owns the revision.
- **GitFlow / release orchestration stays.** The two-tier `feature → dev → main`
  flow, conditional uprev (release only on design change), and the
  design-commit `GIT_HASH` all remain in the workflows. Actions just call `kibot`
  instead of `kicad-cli`.

## Pipeline shape

- **`dev-checks`** (feature→dev, dev→main PRs): ERC / DRC / BOM-LCSC **gates run
  on `kicad-cli`** so the `ENFORCE=false` bring-up toggle stays in our hands
  (KiBot preflights would hard-gate immediately). **KiBot generates the doc
  outputs** — schematic PDF, assembly drawings, iBOM — from the shared
  `usb3_fiber.kibot.yaml`, so dev and release render them the same way.
- **`main-release`** (merge to main): inject provenance → KiBot generates the
  full turnkey package (gerbers, drill, rotation-corrected CPL, JLCPCB BOM, iBOM,
  3D renders, STEP, schematic PDF, assembly drawings) → publish under the rev.

## The order-turnkey checklist (human side)

Tooling makes the outputs; a real order also needs:
1. **Every assembled part has an `LCSC`** number (the BOM gate enforces this).
2. **Do-not-place parts flagged** (no LCSC / DNP) so they're excluded.
3. Cost tuning: prefer JLCPCB **basic** parts over **extended** where practical.

## Open config decisions

- **`only_smd`** in the position file — `true` = SMT-only CPL (JLCPCB SMT
  service); set `false` if you want THT parts (SFP cage, USB, etc.) in the CPL
  for full turnkey. **Defaulted to `false`** here so nothing assembled is missing
  from placement; revisit per how you order.
- Container/runner: the KiBot Docker image pinned to KiCad 10.

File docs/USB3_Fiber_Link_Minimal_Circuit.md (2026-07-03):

# USB3-over-Fiber Minimal Circuit Design
## DS100BR111 Redriver + SFP+ Optical Link

**Project:** Remote ADC SDR Receiver  
**Scope:** Minimum viable circuitry for USB3 SuperSpeed over optical fiber. Single PCB serves both host-side and remote-side roles via jumper selection. The DS100BR111 redriver is configured entirely by pin-strap resistors set at board assembly. The MCP2221A provides the SFP+ management interface and GPIO for TX_DISABLE and RX_LOS. No microcontroller, no firmware, no EEPROM, no Windows toolchain.

---

## Architecture Overview

```
USB3-A connector                              SFP+ cage
(SuperSpeed pairs)                            (optical module)
      |                                             |
      |  INB+/INB-   ┌─────────────────┐  INA+/INA-|
      └──────────────┤                 ├────────────┘
                     │   DS100BR111    │
      ┌──────────────┤   (pin mode,    ├────────────┐
      |  OUTA+/OUTA- │   3.3V)        │  OUTB+/OUTB-|
USB3-A connector     └─────────────────┘        SFP+ cage
(SuperSpeed pairs)         |                         |
                     [pin-strap                 [SFP+ module]
                      resistors]                     |
                                              [optical fiber]

                     ┌──────────┐
                     │ MCP2221A │── USB micro-B ── laptop
                     └──────────┘
                          |
                    SDA/SCL bus
                          |
                    ┌─────┴──────┐
                    │            │
               SFP+ A0h      SFP+ A2h
               (0x50)         (0x51)
               identity      diagnostics
```

**Channel assignment:**

```
A-channel:  INA  ← SFP+ RD+/RD-  (received optical data, post-CDR)
            OUTA → USB3-A SS TX   (SuperSpeed to host or FX3)

B-channel:  INB  ← USB3-A SS RX  (SuperSpeed from host or FX3)
            OUTB → SFP+ TD+/TD-  (data to transmit laser)
```

Each fiber link requires two boards — one at the antenna, one at the shack. Both are identical PCBs; jumpers JP1 and JP2 select the role. The USB3 data path is fully symmetric: the DS100BR111 is bidirectional and the SFP+ module handles both TX and RX in a single cage.

---

## Central Hypothesis

**This prototype exists to test one thing:**

> 10GbE SR SFP+ optical modules will transport USB3 SuperSpeed signalling intact — including LFPS bursts, link training sequences, electrical idle transitions, spread-spectrum clock modulation, and receiver detection — without modification to the modules or the USB3 endpoints.

This has been demonstrated by others in the amateur radio and USB extension communities, but it is not guaranteed by any specification. The Ethernet SFP+ module was not designed for this application. Its internal CDR, limiting amplifier, and signal detect logic were optimised for continuous 10GbE data streams, not for the PHY handshaking behaviours that USB3 requires during link training.

### What Could Go Wrong

```
USB3 PHY behaviour     Risk through the chain
--------------------   -------------------------------------------------------
LFPS bursts            Low-amplitude (~200–400 mVpp), burst-mode signal.
(link training,        Two gatekeepers in series, either of which can eat it:
U-state transitions)
                       (1) DS100BR111: if SD_TH is set too high or the
                       idle-to-active wake response is too slow, the redriver
                       declares idle on inter-burst gaps and fails to pass the
                       burst cleanly. This is the more controllable risk —
                       SD_TH and MODE address it directly.

                       (2) SFP+ module: CDR may not lock on short bursts;
                       limiting amplifier may suppress low-amplitude bursts;
                       LOS logic may assert on inter-burst gaps and squelch
                       output mid-sequence. This is not controllable from
                       outside the module — it is addressed by module
                       selection.

                       The redriver risk is resolved first. If LFPS still
                       fails after SD_TH tuning, the module is the suspect.

Electrical idle        Zero-amplitude gap in the SS data stream.
                       Again two gatekeepers:

                       (1) DS100BR111: SD_TH controls not only when idle is
                       declared but how quickly the redriver wakes back up
                       when signal resumes. A sluggish idle-to-active response
                       clips the leading edge of the next LFPS burst or
                       ordered set. MODE=High (Continuous Talk) is necessary
                       but not sufficient — SD_TH must also be biased toward
                       fast wake-up for reliable LFPS handling.

                       (2) SFP+ module: modules with output squelch gate TX
                       output when LOS asserts — which it will during idle.
                       DS100BR111 Continuous Talk does not prevent the SFP+
                       module's own squelch from firing. This remains the
                       primary uncontrolled risk in the design.

SSC clock modulation   USB3 host controllers spread the 5 Gbps reference
(±5000 ppm)            ±5000 ppm to reduce EMI. The SFP+ CDR must track this
                       continuously. 10GbE SR CDRs are specified for Ethernet
                       SSC profiles, which differ from USB3. Most modern CDRs
                       have sufficient capture range; older or narrow-band CDRs
                       may lose lock and introduce jitter.

Receiver detection     USB3 host asserts a DC test current and measures
                       termination impedance to confirm device presence.
                       This test occurs before any AC signalling. The AC
                       coupling in the signal path must not prevent this DC
                       current from reaching the far-end termination.
                       In practice the internal AC coupling of most SFP+
                       modules blocks the DC test — receiver detection may
                       fail or require a different termination arrangement.

Link training          TS1/TS2 ordered sets at 5 Gbps. These are standard
ordered sets           data patterns and should pass through any CDR with
                       adequate bandwidth. This is the lowest-risk behaviour.
```

### Why the Hypothesis Is Plausible

The CDR in a 10GbE SR module operates at 10.3125 Gbps, well above the 5 Gbps USB3 data rate. USB3 SS data patterns are within the CDR's operating range as a subset of its bandwidth. Community experience (primarily in USB-over-fiber projects using similar hardware) suggests that the CDR tracks SSC adequately and passes link training ordered sets. The primary failure modes in practice are LFPS propagation and electrical idle handling — and these have two components each: redriver idle behaviour (controllable via SD_TH and MODE) and module squelch behaviour (addressed by module selection).

MODE=High and careful SD_TH selection reduce the redriver to a transparent relay for burst signalling. That removes one gatekeeper from the equation. Whether the SFP+ module is also transparent to LFPS and idle is the central experimental question.

### Module Vendor Is a Primary Variable

Two 10GbE SR modules from different vendors may produce completely different results for USB3 transport. The CDR implementation, LOS threshold, squelch hysteresis, and any vendor-specific firmware loaded at manufacture all affect compatibility. **Module vendor must be treated as a first-order experimental variable, not a detail to be resolved after the board is built.**

The Finisar FTLX8571D3BCL is the recommended starting point because it is well-characterised, widely used in community USB-over-fiber experiments, and available in large quantities on the surplus market. It is not guaranteed to work, but it is the most likely to work based on available evidence.

### What the Prototype Validates

A successful Stage 2 optical test (sustained USB3 SuperSpeed transfer at > 300 MB/s through the fiber link, with stable enumeration and no errors) constitutes validation of the hypothesis **for the specific combination of modules used**. It does not validate the hypothesis for all SFP+ modules. Changing module vendor requires repeating the validation.

---

One PCB design serves both ends of the fiber link. Two 3-pin jumpers select the role at assembly time.

```
JP1 — VBUS power source
  Pins 1-2 (host role):    USB3-A VBUS → LDO input
  Pins 2-3 (remote role):  micro-B VBUS → LDO input

JP2 — USB2 D+/D- routing (for MCP2221A)
  Pins 1-2 (host role):    USB3-A USB2 pair → MCP2221A D+/D-
  Pins 2-3 (remote role):  micro-B D+/D- → MCP2221A D+/D-
```

The micro-B connector is populated on all builds regardless of role. On the remote (antenna) board it is the sole power and MCP2221A interface; on the host (shack) board it remains available as a backup. Both jumpers must be installed before powering the board — an uninstalled jumper leaves the LDO input or MCP2221A USB in an undefined state.

```
Role summary:
  Host board:    USB3-A carries both SuperSpeed data and power
                 micro-B available as backup / secondary MCP2221A port
  Remote board:  USB3-A carries SuperSpeed data only (no VBUS expected)
                 micro-B is primary power and MCP2221A interface
```

---

## Power Supply

The LD1117S33TR (SOT-223) converts the VBUS input (selected by JP1) to the single 3.3V rail that powers all board circuitry.

```
VBUS (5V, via JP1)
    |
[LD1117S33TR — ST Microelectronics]
  Package:   SOT-223
  Output:    3.3V fixed
  Max:       800mA
  Dropout:   ~1.1V @ 800mA — adequate with 5V input
  Cost:      ~$0.40
    |
3.3V rail → DS100BR111 VIN, SFP+ VCC_RX/VCC_TX,
            MCP2221A VDD, pull-up resistors
```

### Power Budget

```
DS100BR111:   ~130mA @ 3.3V  =  0.43W  (both channels active, VOD=1000mVpp)
SFP+ module:  ~300mA @ 3.3V  =  1.00W  (typical 10GbE SR, laser on)
MCP2221A:      ~25mA @ 3.3V  =  0.08W
Misc:           ~20mA @ 3.3V  =  0.07W  (LEDs, pull-ups)
Total 3.3V:   ~475mA          =  1.58W

Total from VBUS input: ~1.6W
USB 2.0 port budget:  2.5W (500mA × 5V) — comfortable margin
USB 3.0 port budget:  4.5W (900mA × 5V) — no concern
LD1117S33TR max:      4.0W (800mA × 5V) — ~2.4W headroom
```

A USB 2.0 port on the micro-B is sufficient to power the board. The micro-B carries no SuperSpeed signals — it is purely power and MCP2221A USB.

### LDO Thermal Considerations

The LD1117S33TR dissipates the voltage difference between VBUS and 3.3V as heat:

```
P_dissipated = (V_in − V_out) × I_load
             = (5.0 − 3.3) × 0.475 A
             ≈ 0.81 W
```

The SOT-223 package can handle this with an adequate copper pour on the exposed tab — a 1 cm² pour tied to the GND plane is sufficient to keep junction temperature below 85°C at room ambient. However, the LDO is mounted adjacent to the SFP+ cage, which is itself a heat source (~1W). Layout must ensure the LDO tab pour does not thermally couple to the SFP+ VCC supply traces.

The LD1117 is appropriate for this prototype. For a production design, a 5V→3.3V synchronous buck regulator is preferred: lower heat, lower output noise, and better efficiency. The prototype prioritises simplicity and single-sourcing over efficiency.

```
LDO input:  100nF + 10µF to GND, within 5mm of LDO input pin
LDO output: 100nF + 10µF to GND, within 5mm of LDO output pin
```

---

## DS100BR111 Configuration — Pin Mode

The DS100BR111 is configured entirely by resistors at board assembly. No EEPROM, no software, no tools. The device reads pin states at power-on and runs autonomously.

### 3.3V Operation

The DS100BR111 operates in 3.3V mode on this board. Power pin behaviour differs from the 2.5V mode and must be understood before laying out the schematic.

```
VIN (pin 15):    Connect to 3.3V rail. Primary power input.
                 100nF + 10µF decoupling to GND close to pin.

VDD (pins 21,22): Do NOT connect to 3.3V rail.
                  In 3.3V mode VDD is the internal LDO output,
                  not a supply input. Connecting VDD to the rail
                  back-drives the LDO. Decoupling caps (100nF each)
                  to GND only — no supply connection.

VDD_SEL (pin 16): Tie to GND. Selects 3.3V mode (LDO enabled).
                  If left floating, device enters 2.5V mode and
                  requires an external 2.5V supply on VDD.
```

### 4-Level Pin Encoding

EQ, DEM, VOD_SEL, MODE, and SD_TH are all 4-level pins. Each has an internal 30 kΩ pull-up and 60 kΩ pull-down. The external resistor sets one of four levels:

```
Level   External resistor       State
  3     1 kΩ to VIN (3.3V)     Logic High
  2     No connect (float)      Float
  1     20 kΩ to GND            Mid-low
  0     1 kΩ to GND             Logic Low
```

In 3.3V mode, Level 3 pull-up resistors must reference VIN, not VDD — VDD is not a supply rail in this mode.

### Pin-Mode Resistor Table

```
Pin              Setting    Resistor           Rationale
---------------  ---------  -----------------  ------------------------------------
ENSMB (pin 3)    Level 0    1 kΩ to GND        Enables pin control mode.
                                               Non-negotiable.

MODE (pin 18)    Level 3    1 kΩ to VIN        10GbE Continuous Talk.
                                               USB3 uses LFPS for electrical idle,
                                               not SAS/SATA OOB. SAS mode (Level 0)
                                               would gate on OOB bursts and suppress
                                               LFPS, preventing SS enumeration.
                                               Continuous Talk bypasses all OOB
                                               detection — outputs stay active
                                               whenever signal exceeds SD_TH.

EQA0 (pin 10)    Level 0    1 kΩ to GND        Minimum EQ on INA (SFP+ → OUTA).
EQA1 (pin 9)     Level 0    1 kΩ to GND        INA receives post-CDR output from
                                               the SFP+ module's internal limiting
                                               amplifier. The CDR has already
                                               re-timed and re-driven the data;
                                               the eye is fully open. Board trace
                                               is under 2cm. EQ on a clean signal
                                               amplifies noise, not signal.

EQB0 (pin 1)     Level 0    1 kΩ to GND        Starting point for INB (USB3-A → OUTB).
EQB1 (pin 2)     Level 2    No connect         INB receives USB3 SS from host via
                            (4-level footprint) ~0.5m cable. Cable loss is ~3–6 dB
                                               at 2.5 GHz — a real but modest channel.
                                               One step above minimum is a reasonable
                                               first guess; actual optimal value
                                               depends on the specific cable and
                                               PCB stackup, and must be confirmed
                                               during bring-up. Populate EQB pins as
                                               4-level footprints for resistor-swap
                                               tuning without PCB rework.

DEMA (pin 4)     Level 0    1 kΩ to GND        0 dB de-emphasis on OUTA (→ USB3).
                                               Host RX has its own CTLE/DFE.
                                               0.5m cable is within host EQ range.

DEMB (pin 5)     Level 0    1 kΩ to GND        0 dB de-emphasis on OUTB (→ SFP+).
                                               Sub-2cm trace; SFP+ module CDR
                                               handles it. De-emphasis here would
                                               reduce eye amplitude with no benefit.

VOD_SEL (pin 17) Level 2    No connect         ~1000 mVpp output swing.
                                               SFP+ CML input spec: 150–1200 mVpp.
                                               1000 mVpp is solidly mid-range.
                                               Note: OUTA is hardware-limited to
                                               700 mVpp in pin mode regardless of
                                               VOD_SEL setting (TI datasheet §7.4).
                                               700 mVpp is within USB3 RX spec.

SD_TH (pin 14)   Level 2    No connect         Default starting point (assert 180 mVpp,
                            (adjust early       deassert 110 mVpp).
                            if enum fails)      SD_TH is a first-order bring-up
                                               setting, not a secondary tuning pin.
                                               It controls not only the signal-present
                                               threshold but how quickly the redriver
                                               wakes from idle. A threshold too high
                                               causes the redriver to declare idle on
                                               LFPS inter-burst gaps, clipping the
                                               leading edge of the next burst and
                                               preventing link formation entirely.
                                               If enumeration is intermittent or never
                                               succeeds, SD_TH is the first adjustment
                                               — before EQ, before DEM. See Bring-Up
                                               Adjustment Path.

TX_DIS (pin 6)   Low        GND direct         Both channels always enabled.
                                               TX_DIS=High disables OUTB only.

VDD_SEL (pin 16) Low        GND direct         3.3V operation (see above).
```

**Schematic note — dual-function pins:** Pins 4 and 5 are labelled SDA/DEMA and SCL/DEMB in the datasheet, with the SMBus name listed first. In pin mode (ENSMB = GND) these pins are DEMA and DEMB — de-emphasis resistors to GND. Do not connect them to the I2C bus. Doing so would wire SDA and SCL directly to the de-emphasis resistors and to GND, holding the I2C bus permanently low while shorting the resistors. This must be called out as an explicit schematic note.

### Signal Integrity Margin

The resistor values above are derived from first principles for the stated geometry (sub-2cm board traces, ~0.5m USB3 cable). Whether they are adequate in practice depends on PCB stackup, connector quality, return path continuity, and AC coupling cap placement — none of which are known until the board is built and measured.

The settings should be treated as a starting point, not a guaranteed operating point. USB3 compliance requires a specific eye diagram opening at the receiver; whether the default settings achieve this must be confirmed by measurement. The 4-level footprints on EQB are specifically intended to make this adjustment without PCB rework.

### Bring-Up Adjustment Path

These are expected adjustments during bring-up, not rare exceptions. The ordering matters: idle and signal-detect issues prevent the link from ever forming; EQ and DEM issues only appear after the link is stable.

```
Symptom                            Adjustment
---------------------------------  -----------------------------------------------
Enumeration intermittent or        SD_TH: try 20 kΩ to GND (Level 1, lower
never succeeds                     threshold, faster wake-up from idle). First
                                   knob to move before touching anything else.
                                   If this fixes it, the redriver was the gatekeeper.
                                   If not, the SFP+ module is suspect — swap vendor.

USB3 enumerates at HS (480 Mbps)   SS link training failed. Try SD_TH if not already
not SuperSpeed (5000 Mbps)         done. Then module vendor swap before EQ changes.

USB3 cable RX eye marginal         EQB: increase via resistor swap (consult Table 3).
(link is up but marginal)          This is a signal integrity issue, not idle/burst.

ISI at USB3 host RX                DEMA: no connect → -3 dB (float → Level 2)
(link is stable, payload suffers)

ISI at SFP+ module input           DEMB: no connect → -3 dB (float → Level 2)

OUTA amplitude inadequate          Not adjustable in pin mode (700 mVpp fixed).
                                   Switch ENSMB to SMBus slave if >700 mVpp needed.
```

### Note on Rejected EEPROM Configuration Path

EEPROM boot mode (ENSMB = float) was evaluated and rejected for this design. The reasons are documented here for future reference:

The DS100BR111 in EEPROM master mode hardcodes its EEPROM read to I2C address 0xA0 (7-bit: 0x50). This is the same address as the SFP+ module's A0h management page — a fixed address defined by the SFF-8472 specification and shared by every SFP+ module ever made. The conflict cannot be resolved without an I2C multiplexer (TCA9548A). Additionally, the EEPROM data format is a TI-proprietary binary structure generated by TI's SigCon Architect tool (Windows-only, no open-source equivalent). The sum of added complexity — discrete EEPROM, I2C mux, Windows toolchain, boot sequencing logic — exceeds any benefit for a fixed-geometry application. Pin-strap mode requires seven resistors, set once at assembly, with no toolchain dependencies.

---

## Pin-by-Pin Connection Reference

### SFP+ Cage — 20-Pin Edge Connector (SFF-8472)

```
Pin   Name         Connect?   Connection / Treatment
----  -----------  ---------  -------------------------------------------------
  1   VEE TX GND   MUST       PCB GND plane
  2   TX_FAULT     IGNORE     Leave unconnected. No action available on TX_FAULT
                              in pin mode; optical modules typically do not assert.
  3   TX_DISABLE   MUST       MCP2221A GP0/pin 2 (GPIO_OUT, active HIGH disables laser).
                              Default LOW = laser enabled.
  4   SDA          MUST       MCP2221A SDA + 4.7 kΩ pull-up to 3.3V
  5   SCL          MUST       MCP2221A SCL + 4.7 kΩ pull-up to 3.3V
  6   MOD_ABS      OPTIONAL   Open-drain, pulled LOW by module when seated.
                              10 kΩ pull-up to 3.3V; connect to MCP2221A GPIO
                              for module-present detection, or leave unconnected.
  7   RS0          IGNORE     Rate select for dual-rate SFP devices.
                              All 10G SR/LR modules ignore this. Leave open.
  8   RX_LOS       MUST       330 Ω to red LED (LOS indicator) + MCP2221A GP1/pin 6
                              (GPIO_IN). Active HIGH = no received optical signal.
                              10 kΩ pull-up to 3.3V (LOS is open-drain).
  9   RS1          IGNORE     Same as RS0. Leave unconnected.
 10   VEE RX GND   MUST       PCB GND plane
 11   VEE RX GND   MUST       PCB GND plane
 12   RD-          MUST       DS100BR111 INA- (100Ω diff, 100nF AC coupling)
                              SFP+ module provides internal AC coupling on RD
                              outputs; these caps are technically redundant but
                              are retained per DS100BR111 application circuit and
                              as insurance against modules that do not.
 13   RD+          MUST       DS100BR111 INA+ (100Ω diff, 100nF AC coupling)
                              Same rationale as RD-.
 14   VEE RX GND   MUST       PCB GND plane
 15   VCC_RX       MUST       3.3V via 10 Ω series + 100nF to GND
 16   VCC_TX       MUST       3.3V via 10 Ω series + 100nF to GND
 17   VEE TX GND   MUST       PCB GND plane
 18   TD+          MUST       DS100BR111 OUTB+ (100Ω diff, 100nF AC coupling)
                              Required by SFF-8431: AC coupling on TD lines is the
                              host board's responsibility, not the module's.
 19   TD-          MUST       DS100BR111 OUTB- (100Ω diff, 100nF AC coupling)
                              Same — SFF-8431 mandates these caps on this side.
 20   VEE TX GND   MUST       PCB GND plane
```

VCC5 (5V supply pin, some cage footprints): omit unless module datasheet
requires it. The FTLX8571D3BCL and all 10G SR modules used in this design
are 3.3V-only. Verify byte 65 of A0h (nominal supply voltage) after first
module seating if using unfamiliar modules.

---

### DS100BR111 — 24-Pin WQFN (Pin Mode, 3.3V)

```
Pin   Name              Connect?   Connection / Treatment
----  ----------------  ---------  ------------------------------------------------
  1   EQB0/AD3          MUST       1 kΩ to GND (EQB0 = Level 0)
  2   EQB1/AD2          MUST       No connect — float (EQB1 = Level 2).
                                   Populate as 4-level footprint for bring-up tuning.
  3   ENSMB             MUST       1 kΩ to GND (pin mode)
  4   SDA/DEMA          MUST       1 kΩ to GND (DEMA = Level 0, 0 dB de-emphasis).
                                   *** PIN MODE ONLY: this is DEMA, not SDA. ***
                                   Do NOT connect to I2C bus.
  5   SCL/DEMB          MUST       1 kΩ to GND (DEMB = Level 0, 0 dB de-emphasis).
                                   *** PIN MODE ONLY: this is DEMB, not SCL. ***
                                   Do NOT connect to I2C bus.
  6   TX_DIS            MUST       GND direct (both channels always enabled)
  7   OUTA+             MUST       USB3-A SS TX+ (100Ω diff, 100nF AC coupling)
  8   OUTA-             MUST       USB3-A SS TX- (100Ω diff, 100nF AC coupling)
  9   AD1/EQA1          MUST       1 kΩ to GND (EQA1 = Level 0, min EQ)
 10   AD0/EQA0          MUST       1 kΩ to GND (EQA0 = Level 0, min EQ)
 11   INB+              MUST       USB3-A SS RX+ (100Ω diff, 100nF AC coupling)
                                   FX3 has its own AC coupling caps on its SS TX
                                   outputs. These caps are local input bypass for
                                   the DS100BR111 per its application circuit.
                                   Two caps in series across the cable (~50nF
                                   effective) is harmless at 5 Gbps.
 12   INB-              MUST       USB3-A SS RX- (100Ω diff, 100nF AC coupling)
                                   Same rationale as INB+.
 13   LOS               NC         Leave unconnected. In pin mode LOS monitors INA
                                   (SFP+ received signal) only — same condition as
                                   SFP+ RX_LOS on pin 8. Redundant with existing
                                   LED and MCP2221A GP1. DNP 10 kΩ pull-up footprint
                                   to 3.3V retained for potential future use.
 14   SD_TH             MUST       No connect — float (default starting point).
                                   First-order bring-up setting. See pin-mode
                                   resistor table and Bring-Up Adjustment Path.
 15   VIN               MUST       3.3V supply. 100nF + 10µF to GND. Primary power.
 16   VDD_SEL           MUST       GND direct (3.3V mode)
 17   VOD_SEL/READEN    MUST       No connect — float (VOD = 1000 mVpp).
                                   In pin mode this pin is VOD_SEL, not READEN.
 18   MODE/DONE         MUST       1 kΩ to VIN (3.3V). Continuous Talk mode.
                                   In pin mode this pin is MODE, not DONE.
 19   OUTB-             MUST       SFP+ TD- (100Ω diff, 100nF AC coupling)
 20   OUTB+             MUST       SFP+ TD+ (100Ω diff, 100nF AC coupling)
 21   VDD               MUST       100nF to GND ONLY. Not connected to supply.
 22   VDD               MUST       100nF to GND ONLY. Not connected to supply.
 23   INA-              MUST       SFP+ RD- (100Ω diff, 100nF AC coupling)
 24   INA+              MUST       SFP+ RD+ (100Ω diff, 100nF AC coupling)
 DAP  GND (thermal pad) MUST       PCB GND plane, minimum 4 vias. This pad is the
                                   sole ground connection for the device. Do not omit.
```

**Resistor BOM:** 6× 1 kΩ 0402 to GND, 1× 1 kΩ 0402 to VIN.
No-connect (float) pads: pins 2, 14, 17. Pins 4 and 5 are GND resistors, not I2C.

---

### MCP2221A — QFN-16 (MCP2221AT-I/ML)

```
Pin   Name    Connect?   Connection / Treatment
----  ------  ---------  ----------------------------------------------------------
  1   VDD     MUST       3.3V supply. 100nF + 10µF to GND close to pin.
  2   GP0     MUST       SFP+ TX_DISABLE (cage pin 3). GPIO_OUT, default LOW.
                         330 Ω series resistor protects pin if accidentally
                         reconfigured as input while SFP+ TX_DISABLE is driven.
  3   RESET#  MUST       10 kΩ pull-up to 3.3V. Active LOW reset input.
                         Internal pull-up exists but external resistor improves
                         noise immunity during power ramp.
  4   UARTRX  IGNORE     UART not used. Leave unconnected.
                         Internal pull-up holds HIGH. UART CDC port enumerates
                         on host regardless; does not affect I2C/HID operation.
  5   UARTTX  IGNORE     UART not used. Leave unconnected.
  6   GP1     MUST       SFP+ RX_LOS (cage pin 8). GPIO_IN.
                         Active HIGH = no received optical signal.
                         330 Ω series resistor.
  7   GP2     OPTIONAL   Unassigned on first build. Footprint present.
                         Candidate: heartbeat LED (GPIO_OUT, toggled at 1 Hz
                         by host script; confirms MCP2221A communication path).
                         330 Ω series resistor to LED if populated.
  8   GP3     OPTIONAL   Unassigned on first build. Footprint present.
  9   SCL     MUST       SFP+ SCL (cage pin 5). 4.7 kΩ pull-up to 3.3V on bus.
 10   SDA     MUST       SFP+ SDA (cage pin 4). 4.7 kΩ pull-up to 3.3V on bus.
                         Direct connection — no mux required (DS100BR111 not
                         on this bus in pin mode).
 11   VSS     MUST       GND
 12   VUSB    MUST       100nF to GND ONLY. Output of internal USB LDO.
                         Do NOT connect to 3.3V supply rail — back-drives LDO.
 13   D-      MUST       USB micro-B D- (via JP2)
 14   D+      MUST       USB micro-B D+ (via JP2)
 15   NC      IGNORE     No connection.
 16   NC      IGNORE     No connection.
 EP   EP      MUST       Exposed pad. GND. Solder to GND copper pour with
                         minimum 4 vias under pad.
```

**GP pin assignment:**

```
GP0  OUT   SFP+ TX_DISABLE   HIGH = laser off; default LOW = laser on
GP1  IN    SFP+ RX_LOS       HIGH = no received optical signal
GP2  —     Unassigned, footprint only (heartbeat LED candidate)
GP3  —     Unassigned, footprint only
```

**I2C bus note:** In pin mode the DS100BR111 is not on the I2C bus at all. The MCP2221A talks exclusively to SFP+ A0h (0x50) and A2h (0x51). No address conflicts exist. No mux is required.

---

### Cross-Device Connection Summary

```
Signal              From                     To
------------------  -----------------------  -----------------------------
SFP+ RD+/RD-        SFP+ pins 13/12          DS100BR111 INA+/INA- (AC)
SFP+ TD+/TD-        DS100BR111 OUTB+/OUTB-   SFP+ pins 18/19 (AC)
USB3 SS TX+/TX-     DS100BR111 OUTA+/OUTA-   USB3-A SS TX pins (AC)
USB3 SS RX+/RX-     USB3-A SS RX pins        DS100BR111 INB+/INB- (AC)
SFP+ SDA            SFP+ cage pin 4          MCP2221A SDA (+ 4.7 kΩ pull-up)
SFP+ SCL            SFP+ cage pin 5          MCP2221A SCL (+ 4.7 kΩ pull-up)
SFP+ TX_DISABLE     MCP2221A GP0             SFP+ cage pin 3 (330 Ω series)
SFP+ RX_LOS         SFP+ cage pin 8          MCP2221A GP1 + LOS LED (330 Ω)
MCP2221A D+/D-      USB micro-B              MCP2221A pins 14/13 D+/D- (via JP2)
```

All eight AC coupling capacitors on DS100BR111 CML paths are 100nF 0402, placed
within 2mm of the DS100BR111 pins on the DS100BR111 side of each pair. The OUTB caps
(SFP+ TD side) are mandatory per SFF-8431 — the host board owns this coupling. The INA
caps (SFP+ RD side) and INB caps (USB3 side) are redundant with coupling provided by
the SFP+ module and FX3 respectively, but are retained per DS100BR111 application
circuit guidance.

---

## LEDs and Diagnostic Indicators

### LED Polarity Convention

**Lit = problem, dark = healthy** — except PWR which is the opposite.
A fully operational board in a dark room shows one green LED. This convention
is standard in telecom hardware and minimises misreading during bring-up.

### LED Definitions

```
Silkscreen  Colour  Drive                Resistor  Lit Means           Dark Means
----------  ------  -------------------  --------  ------------------  ----------------
PWR         Green   LD1117S33TR output   1 kΩ      Board is powered    Board unpowered
LOS         Red     SFP+ RX_LOS pin 8   330 Ω     No optical signal   Fiber link live
SPARE       Green   MCP2221A GP2/pin 7 (DNP) 330 Ω (unpopulated)   (unpopulated)
```

**PWR:** Confirms the LDO has output and the 3.3V rail is live. Hardware-driven,
always on when powered. Does not confirm jumper state, module seating, or
USB3 enumeration — it is purely a power-on indicator.

**LOS (Loss of Signal):** Driven directly by the SFP+ module's internal optical
power monitor. No firmware or host involvement required. Valid as soon as the
module is seated and powered, before any USB enumeration. Asserts when received
optical power drops below ~-17 dBm (typical for 10G SR modules).

**LED state matrix:**

```
PWR     LOS     Interpretation
------  ------  ---------------------------------------------------------
dark    dark    Board unpowered (both expected when off)
lit     lit     Board powered, no fiber or far end not transmitting
lit     dark    Optical signal present — normal operating state
```

There is no state in which PWR is dark and LOS is lit (LOS is open-drain;
it has no drive when the module is unpowered).

**SPARE footprint:** One green LED footprint is present but unpopulated on
the first build. Recommended use: heartbeat, driven by MCP2221A GP2 (pin 7) toggled
at 1 Hz by the host diagnostic script. Confirms the entire MCP2221A
communication path is healthy at a glance. Requires three lines of Python.

---

## Diagnostics Beyond the LEDs

The LEDs give binary go/no-go. The following gives numbers.

### MCP2221A — SFP+ Management Interface

The MCP2221A appears on the host as a USB HID device (EasyMCP2221 Python
library) and optionally as a CDC COM port (Microchip GUI tool). No driver
installation required on Linux or macOS.

**GPIO reads (binary):**

```
GP0  Write  SFP+ TX_DISABLE  Assert high to disable laser; low to enable
GP1  Read   SFP+ RX_LOS      Same signal as LOS LED, readable in software
GP2  Write  Spare LED        Heartbeat toggle if populated
GP3  —      Unassigned
```

**SFP+ A0h (0x50) — static identity, read at first bring-up:**

```
Bytes    Field                   Example (FTLX8571D3BCL)
-------  ----------------------  ----------------------------------
0        Identifier              0x03 = SFP
2        Connector               0x07 = LC
3–10     Compliance              10G SR, 850nm
12       BR nominal (×100Mbps)   0x67 = 10.3 Gbps
20–35    Vendor name             "FINISAR CORP   "
40–55    Vendor part number      "FTLX8571D3BCL  "
60–61    Wavelength              850 nm
84–91    Date code
92–94    Diagnostic type         0x68 = DDM supported, internal cal
```

Read A0h first. Confirms module is seated and responsive, DDM is supported,
and part identity matches expectations before attempting A2h reads.

**SFP+ A2h (0x51) — live diagnostics, update in real time:**

```
Bytes    Field            Units      Healthy range (SR module, room temp)
-------  ---------------  ---------  ------------------------------------
96–97    Temperature      °C × 256   0–70°C
98–99    Supply voltage   100 µV     3.1–3.5V
100–101  TX bias current  2 µA       5–100 mA (zero = laser off or dead)
102–103  TX output power  0.1 µW     -3 to +3 dBm typical
104–105  RX input power   0.1 µW     > -11 dBm for a working link
```

These five measurements are the primary quantitative diagnostics for the fiber
link and are available before USB3 enumeration is attempted.

**Link margin:**

```
margin (dB) = RX_power_dBm − module_sensitivity_dBm
```

For FTLX8571D3BCL: sensitivity = −11.1 dBm. On a 1m OM3 patch with 0.5 dB
insertion loss and −3 dBm TX power: margin ≈ 7.6 dB. Anything above 3 dB is
comfortable. Below 1 dB warrants investigation before proceeding to USB3 tests.

### USB3 Enumeration (Host OS)

```
Linux:    lsusb -t           confirms SuperSpeed (5000M) negotiated
          dmesg | grep usb   shows SS link negotiation messages
Windows:  Device Manager     shows "USB3" or "SuperSpeed" annotation
```

If the device enumerates at High Speed (480 Mbps) instead of SuperSpeed, the SS
link has fallen back. Check cable, FX3 firmware, and DS100BR111 signal integrity.

### USB3 Throughput (Host Software)

The FX3 with SDDC_FX3 firmware streams data as a bulk USB endpoint. Throughput
is directly measurable with SDR host software or a raw USB benchmark. Expected:
> 300 MB/s sustained for a healthy SuperSpeed link. Sustained below 200 MB/s
with no errors suggests SS speed fallback.

### DS100BR111 (Pin Mode — No Register Access)

No register readback is available in pin mode. The device is fully transparent
once powered. The observable outcome is either correct USB3 operation or not.

**SMBus slave mode escape hatch:** If register readback becomes necessary during
a difficult bring-up, switching to SMBus slave mode requires: replace the 1 kΩ
ENSMB resistor to GND with 1 kΩ to VIN; populate SDA/SCL pull-up resistors
(2–5 kΩ to 3.3V); connect MCP2221A GP2 (pin 7) / GP3 (pin 8) to the SDA/SCL pads. PCB footprints
for all of this are present but DNP on first build. Note: in SMBus slave mode
the DS100BR111 shares the I2C bus at an address that must be kept clear of 0x50
and 0x51, and SFP+ A0h can only be accessed when the DS100BR111 is not also
being addressed (time-multiplexed access required).

---

## SFP+ Module Selection

**Module vendor is a first-order experimental variable.** Two 10GbE SR modules from different vendors may behave completely differently for USB3 transport. CDR implementation, LOS threshold, output squelch behaviour, and any vendor firmware loaded at manufacture all affect USB3 compatibility independently of the module's optical performance. A module that passes optical diagnostics may still fail USB3 link training.

### Why Vendor Matters

```
Variable                Impact on USB3 transport
----------------------  ---------------------------------------------------
CDR capture range       Must track USB3 SSC (±5000 ppm). Wide-capture CDRs
                        (common in 10GbE SR) generally cope; narrow-band CDRs
                        (some older or storage-class modules) may lose lock.

LOS assert threshold    If LOS asserts during electrical idle or LFPS gaps,
and squelch behaviour   the module may gate TX output mid-training sequence.
                        This kills enumeration even if the redriver is in
                        Continuous Talk mode. Threshold and squelch hysteresis
                        vary by vendor and are not always documented.

Limiting amplifier      Optimised for Ethernet data patterns; may respond
response                differently to LFPS bursts (~250 MHz, short duty
                        cycle) than to continuous 5 Gbps data.

Vendor firmware         Some modules contain embedded microcontrollers that
                        monitor diagnostics and can alter module behaviour.
                        Batch variation within the same part number is possible.
```

### Recommended Starting Module: Finisar FTLX8571D3BCL

```
Vendor:        Finisar (now II-VI / Coherent)
Part:          FTLX8571D3BCL
Data rate:     10.3125 Gbps
Wavelength:    850nm VCSEL
Fiber:         OM3/OM4 multimode, LC duplex
Typical reach: 300m OM3, 400m OM4
CDR:           Wide capture range, known good for USB3 in community use
DDM:           Full SFF-8472 A2h diagnostics
Availability:  Commodity surplus — large quantities on eBay, ~$5–15
```

This module is the recommended first choice because it has been used successfully for USB3-over-fiber by others. It is not guaranteed to work, and **each batch sourced from surplus must be validated**, as firmware variants within the same part number have been reported.

### Alternative: Avago / Broadcom AFBR-703SDZ

Similar specifications to the FTLX8571D3BCL. Known good for USB3 transport in community use. Use as a second option if Finisar is unavailable.

### Alternative: 8GFC (8 Gigabit Fibre Channel)

```
Data rate:     8.5 Gbps line rate
Wavelength:    850nm VCSEL
Fiber:         OM3/OM4, LC duplex
CDR:           Typically narrower capture range than 10GbE SR
               May be less tolerant of USB3 SSC
```

8GFC modules are on the same hardware platform as 10GbE SR but with different CDR tuning. Try 10GbE SR first.

### Module Compatibility Test Protocol

Before committing to a module for production use, run this minimum test sequence:

```
1. Optical check (A2h):
   Confirm TX bias > 0, RX power within expected range, link margin > 3 dB.
   This tests the module optically but says nothing about USB3 compatibility.

2. USB3 enumeration:
   Connect USB3 device (storage or hub) through the fiber link.
   Confirm SuperSpeed (5000M) enumeration, not High Speed fallback.
   A High Speed fallback means SS link training failed.

3. Sustained transfer:
   Run a 1 GB transfer. Confirm > 300 MB/s, zero errors.
   This exercises SSC tracking and CDR stability under continuous load.

4. Cold start / re-enumeration:
   Power-cycle the USB3 device 10 times and confirm consistent SS enumeration.
   Some modules enumerate correctly once but fail on re-plug if the idle
   handling disrupts the CDR between enumerations.

5. Module swap:
   Repeat with a module from a different batch or different vendor.
   If behaviour differs, the module is a variable — document which modules pass.
```

A module that passes all five stages is validated for this application.

---

## Bill of Materials

| Qty | Part | Package | Function | Approx cost |
|-----|---|---|---|---|
| 1 | DS100BR111 | WQFN-24 | USB3↔SFP+ redriver | ~$10 |
| 1 | SFP+ cage | Standard edge | Module socket | ~$3 |
| 1 | MCP2221A | QFN-16 (MCP2221AT-I/ML) | USB→I2C bridge + GPIO | ~$1.50 |
| 1 | LD1117S33TR | SOT-223 | 5V→3.3V LDO, 800mA | ~$0.40 |
| 1 | USB micro-B | Through-hole | Power + MCP2221A interface | — |
| 1 | USB3-A | Through-hole | SuperSpeed data connector | — |
| 3 | JP1, JP2×2 | 3-pin 2.54mm | Host/remote role select (JP2 is a pair) | — |
| 7 | 1 kΩ 0402 | — | DS100BR111 pin-mode resistors | — |
| 1 | 10 kΩ 0402 | — | RESET# pull-up (MCP2221A) | — |
| 2 | 4.7 kΩ 0402 | — | I2C bus pull-ups (SDA, SCL) | — |
| 2 | 10 kΩ 0402 | — | LOS pull-up + MOD_ABS pull-up | — |
| 2 | 330 Ω 0402 | — | GP0/GP1 series protection (MCP2221A) | — |
| 2 | 10 Ω 0402 | — | SFP+ VCC_RX / VCC_TX series | — |
| 8 | 100nF 0402 | — | DS100BR111 CML AC coupling | — |
| 9 | 100nF 0402 | — | Decoupling (see consolidated reference) | — |
| 4 | 10µF 0805 | — | Bulk decoupling (LDO in/out, DS100BR111 VIN, MCP2221A VDD) | — |
| 1 | LED green | 0805 | PWR indicator | — |
| 1 | LED red | 0805 | LOS indicator | — |
| 1 | LED green | 0805 | SPARE (DNP on first build) | — |
| 1 | 1 kΩ 0402 | — | PWR LED current limit | — |
| 2 | 330 Ω 0402 | — | LOS LED + SPARE LED current limit | — |
| 1 | SFP+ module | — | Finisar FTLX8571D3BCL preferred | ~$5–15 |

**Total active ICs: 2 (DS100BR111 + MCP2221A)**  
**Microcontroller: not required**  
**Firmware: not required on board — MCP2221A driven entirely from host Python**  
**EEPROM: not required — configuration is fully defined by pin-strap resistors**

---

## PCB Layout Rules

Non-negotiable for reliable USB3 SuperSpeed operation:

```
Differential pair impedance:     100Ω ± 10% on all SS and CML pairs
USB3 connector to DS100BR111:    maximum 25mm trace length
DS100BR111 to SFP+ cage:         maximum 15mm trace length
AC coupling cap placement:       within 2mm of DS100BR111 CML pins
Ground plane:                    continuous, unbroken — no splits,
                                 no vias crossing under differential pairs
DS100BR111 thermal pad:          minimum 4 GND vias through DAP
VDD pins 21/22:                  decoupling caps only — no supply connection
VIN pin 15:                      100nF + 10µF, closest caps on board
```

---

## Prototype Validation Sequence

### Step 1 — Board Power-On

```
Power board via micro-B (JP1 set to remote/micro-B role for bench work).
Check PWR LED lit.
Measure 3.3V rail at test point.
Confirm < 500 mV ripple.
```

### Step 2 — MCP2221A Enumeration

```
Connect micro-B to laptop.
Confirm MCP2221A appears as USB HID device (and CDC COM port).
Linux: lsusb shows "Microchip Technology, Inc. MCP2221"
Run: python -c "import EasyMCP2221; print(EasyMCP2221.Device())"
Expected: device object with no errors.
```

### Step 3 — SFP+ Module Identity (A0h)

```
Insert SFP+ module into cage.
Read A0h via MCP2221A:
  mcp.I2C_read(0x50, 16, reg=20)
Verify vendor name and part number.
Confirms: module seated, I2C bus working, DDM supported.
```

### Step 4 — Laser Enable and TX Power (A2h)

```
Confirm GP0 (TX_DISABLE) is LOW (laser enabled — default after power-on).
Read A2h: mcp.I2C_read(0x51, 10, reg=96)
Bytes 0–1: temperature (°C × 256)
Bytes 4–5: TX bias current (2 µA/LSB) — non-zero confirms laser firing
Bytes 6–7: TX output power (0.1 µW/LSB) — convert to dBm, verify in spec
```

### Step 5 — Fiber Insertion and RX Power

```
Connect OM3 LC duplex patch between both boards.
Read A2h on both boards.
Bytes 8–9: RX input power (0.1 µW/LSB) — convert to dBm.
Calculate link margin = RX power − module sensitivity (−11.1 dBm typical).
Healthy: > 3 dB margin on both ends.
LOS LED should extinguish on both boards when fiber is connected.
```

### Stage 1 — Copper DAC Cable (No Fiber)

```
Replace SFP+ modules with a passive SFP+ DAC cable (1m).
Connect USB3 device (storage drive or hub) to far end.
Verify USB3 enumeration through redriver pair.
Run sustained transfer: > 300 MB/s, 1 GB+ with zero errors.
Pass: clean enumeration, full USB3 bandwidth, no errors.
```

### Stage 2 — Optical Link

```
Replace DAC cable with two SFP+ modules + OM3 fiber patch.
Run pre-enumeration A2h checks (Steps 4–5 above).
Verify link margin > 3 dB both ends and LOS LEDs dark.
Connect USB3 device and repeat Stage 1 tests through fiber.
Pass: identical results to Stage 1.

Troubleshooting priority:
  1. Check A2h optical power first — separates optical from USB3 problems
  2. If optical power good but USB3 fails at High Speed: SS link training failed.
     Check EQB resistors. Swap to a known-good module vendor before other steps.
  3. If SS enumerates but is unstable: SSC tracking suspect — try 10GbE SR
     modules from Finisar or Avago before adjusting redriver settings
  4. If SS is stable but throughput is low: check for SS→HS fallback under load,
     then revisit EQ and DEM settings
```

---

## Related Design Constraints

### USB2 Lines

The USB2 differential pair (D+/D−) is deliberately omitted from the fiber data
path. USB2 is a conducted EMI source that would compromise the antenna unit's
noise floor. The FX3 enumerates via SuperSpeed only. This requires FX3 firmware
configured for SuperSpeed-only enumeration and no USB2 fallback in the fiber link.
This is intentional, not an oversight.

### DFU Firmware Loading

USB DFU for FX3 operates over USB2 and is unavailable through the fiber link.
The production antenna unit must boot firmware from SPI NOR flash:

```
Required on antenna PCB:
  SPI NOR flash (e.g. W25Q32 or equivalent)
  6-pin SPI programming header (externally accessible)
  Optional: direct USB connector for bench development (disconnect before field use)
```

See AN76405 (Cypress/Infineon) for FX3 SPI boot implementation details.

---

## What Does Not Require Configuration

| Function | Status |
|---|---|
| Redriver initialization sequence | Not required at runtime — pin straps are read once at power-on |
| SFP+ management interface (I2C) | Not required for data transport — used only for diagnostics |
| Clock or timing input to redriver | Not required |
| Reset sequence beyond power-up | Not required |
| Microcontroller | Not required |
| Firmware | Not required on the board |
| USB protocol awareness | Not required — DS100BR111 is protocol-agnostic |
| EEPROM | Not required — pin straps provide complete configuration |

The DS100BR111 is protocol-transparent. It does not know it is carrying USB3
SuperSpeed. USB3 link negotiation occurs entirely between the FX3 and the host
controller — the redriver is invisible to that process.

---

## Dev Board vs Production Circuit Comparison

| Feature | Dev Board | Production Minimum |
|---|---|---|
| Power input | USB micro-B VBUS (via JP1/JP2) | Dedicated 5V supply |
| 3.3V generation | LD1117S33TR LDO (~0.8W dissipated as heat) | Synchronous buck regulator preferred |
| Board roles | Host or remote, jumper-selected | Dedicated single-role PCB |
| DS100BR111 config | Pin-strap resistors (identical to production) | Pin-strap resistors |
| SFP+ management | MCP2221A I2C + GPIO | Not required — TX_DISABLE tied low |
| LOS monitor | SFP+ RX_LOS → MCP2221A GP1 + LED | Optional LED direct from RX_LOS |
| Diagnostics | Full EasyMCP2221 Python + A2h DDM | A2h readable if I2C wired |
| USB3 data path | Identical | Identical |

The USB3 SuperSpeed data path is **identical in both cases**. The dev board
additions are entirely orthogonal to the signal being transported. A validated
dev board fully validates the production signal path.

---

## JP1 / JP2 Jumper Wiring Detail

Both jumpers are 3-pin 2.54mm headers with a single shorting block selecting one of two positions.

```
JP1 — VBUS source (powers the LD1117S33TR input)

  Pin 1 ── USB3-A VBUS
  Pin 2 ── LDO_IN (common, connects to LD1117S33TR input)
  Pin 3 ── micro-B VBUS

  Shorting pins 1-2: host role (USB3-A VBUS powers board)
  Shorting pins 2-3: remote role (micro-B VBUS powers board)

JP2 — MCP2221A USB2 D+/D- source

  Pin 1 ── USB3-A USB2 D+ (or D-)
  Pin 2 ── MCP2221A D+ (or D-) (common)
  Pin 3 ── micro-B D+ (or D-)

  Shorting pins 1-2: host role (USB3-A USB2 pair to MCP2221A)
  Shorting pins 2-3: remote role (micro-B D+/D- to MCP2221A)

JP2 is a pair of 3-pin headers — one for D+, one for D-.
Both must be shorted in the same position at all times.
Silk screen must label positions: pin 1 = HOST, pin 3 = REMOTE.
```

Board must not be powered with either jumper uninstalled.

---

## Consolidated Decoupling Reference

All capacitors are ceramic unless noted. Place all caps on the same side of the PCB as their associated IC, as close to the relevant pin as the package allows.

```
Location                      Cap       Note
----------------------------  --------  ------------------------------------------
DS100BR111 VIN (pin 15)       100nF     Within 1mm of pin. Primary supply bypass.
DS100BR111 VIN (pin 15)       10µF      Within 5mm. Bulk.
DS100BR111 VDD (pin 21)       100nF     NOT connected to supply — decoupling only.
DS100BR111 VDD (pin 22)       100nF     NOT connected to supply — decoupling only.
DS100BR111 INA+ coupling      100nF     0402. Within 2mm of pin 24, DS100BR111
                                        side. Module provides internal AC coupling;
                                        these caps are redundant but retained.
DS100BR111 INA- coupling      100nF     0402. Within 2mm of pin 23, DS100BR111 side.
DS100BR111 INB+ coupling      100nF     0402. Within 2mm of pin 11, DS100BR111 side.
                                        FX3 has its own caps; double-coupling harmless.
DS100BR111 INB- coupling      100nF     0402. Within 2mm of pin 12, DS100BR111 side.
DS100BR111 OUTA+ coupling     100nF     0402. Within 2mm of pin 7, DS100BR111 side.
DS100BR111 OUTA- coupling     100nF     0402. Within 2mm of pin 8, DS100BR111 side.
DS100BR111 OUTB+ coupling     100nF     0402. Within 2mm of pin 20, DS100BR111 side.
                                        REQUIRED by SFF-8431 — TD-side coupling is
                                        the host board's obligation, not the module's.
DS100BR111 OUTB- coupling     100nF     0402. Within 2mm of pin 19, DS100BR111 side.
                                        Same — SFF-8431 mandated.
MCP2221A VDD (pin 1)          100nF     Within 1mm of pin.
MCP2221A VDD (pin 1)          10µF      Within 5mm. Bulk.
MCP2221A VUSB (pin 12)        100nF     Required. VUSB is LDO output — do not
                                        connect to supply, cap to GND only.
LD1117S33TR input             100nF     Within 2mm of input pin.
LD1117S33TR input             10µF      Electrolytic or tantalum acceptable.
LD1117S33TR output            100nF     Within 2mm of output pin.
LD1117S33TR output            10µF      Required for LDO stability.
SFP+ VCC_RX (cage pin 15)     100nF     After 10Ω series resistor.
SFP+ VCC_TX (cage pin 16)     100nF     After 10Ω series resistor.
```

---

## Schematic Review Checklist

Work through this list against the schematic before sending for layout.

**Power and ground:**
- [ ] LD1117S33TR: input connected to JP1 pin 2 (LDO_IN). Output is 3.3V rail. ADJ pin not present on fixed-voltage variant — confirm correct part number ordered.
- [ ] DS100BR111 VIN (pin 15): connected to 3.3V rail with 100nF + 10µF to GND.
- [ ] DS100BR111 VDD (pins 21, 22): each has 100nF to GND. No connection to 3.3V rail. This is the single most common DS100BR111 schematic error.
- [ ] DS100BR111 VDD_SEL (pin 16): tied directly to GND. Not floated.
- [ ] DS100BR111 DAP (thermal pad): connected to GND net. Appears as a symbol pin or via annotation in KiCAD — confirm it is not floating.
- [ ] MCP2221A VDD (pin 1): connected to 3.3V rail with 100nF + 10µF to GND.
- [ ] MCP2221A VUSB (pin 12): 100nF to GND only. Not connected to 3.3V rail.
- [ ] MCP2221A VSS (pin 11): connected to GND. EP (exposed pad) also to GND, with minimum 4 vias.
- [ ] SFP+ VCC_RX (pin 15) and VCC_TX (pin 16): each has 10Ω series resistor from 3.3V rail, then 100nF to GND at cage pin.
- [ ] All SFP+ VEE pins (1, 10, 11, 14, 17, 20): connected to GND.

**DS100BR111 pin-mode resistors:**
- [ ] ENSMB (pin 3): 1kΩ to GND.
- [ ] MODE (pin 18): 1kΩ to VIN (3.3V rail). Not to VDD.
- [ ] EQA0 (pin 10): 1kΩ to GND.
- [ ] EQA1 (pin 9): 1kΩ to GND.
- [ ] EQB0 (pin 1): 1kΩ to GND.
- [ ] EQB1 (pin 2): no connect / 4-level footprint, no resistor loaded.
- [ ] DEMA (pin 4): 1kΩ to GND. Confirm this pin is NOT connected to SDA. Check pin number against chosen schematic symbol.
- [ ] DEMB (pin 5): 1kΩ to GND. Confirm this pin is NOT connected to SCL. Check pin number against chosen schematic symbol.
- [ ] VOD_SEL (pin 17): no connect / float.
- [ ] SD_TH (pin 14): no connect / float as starting point. Populate as 4-level footprint (20 kΩ to GND pad present but DNP). This is a first-order bring-up adjustment point — see Bring-Up Adjustment Path.
- [ ] TX_DIS (pin 6): GND direct.
- [ ] VDD_SEL (pin 16): GND direct.
- [ ] LOS (pin 13): unconnected. DNP 10kΩ pull-up footprint to 3.3V present but not loaded.

**AC coupling — DS100BR111 CML paths:**
- [ ] INA+ (pin 24): 100nF in series, cap placed on IC side of the differential pair.
- [ ] INA- (pin 23): 100nF in series, cap placed on IC side.
- [ ] INB+ (pin 11): 100nF in series, IC side.
- [ ] INB- (pin 12): 100nF in series, IC side.
- [ ] OUTA+ (pin 7): 100nF in series, IC side.
- [ ] OUTA- (pin 8): 100nF in series, IC side.
- [ ] OUTB+ (pin 20): 100nF in series, IC side.
- [ ] OUTB- (pin 19): 100nF in series, IC side.

**I2C bus:**
- [ ] MCP2221A SDA (pin 10): connected to SFP+ cage SDA (pin 4). 4.7kΩ pull-up to 3.3V on the bus.
- [ ] MCP2221A SCL (pin 9): connected to SFP+ cage SCL (pin 5). 4.7kΩ pull-up to 3.3V on the bus.
- [ ] No other devices on the I2C bus. DS100BR111 SDA/SCL pads are DEMA/DEMB in pin mode — not connected to bus.

**MCP2221A GPIO:**
- [ ] GP0 (pin 2): 330Ω series to SFP+ TX_DISABLE (cage pin 3).
- [ ] GP1 (pin 6): 330Ω series from SFP+ RX_LOS (cage pin 8). Also connects to LOS LED (330Ω to LED to GND) and 10kΩ pull-up to 3.3V.
- [ ] GP2 (pin 7): footprint only. No active connection. 330Ω series to spare LED footprint if populated.
- [ ] GP3 (pin 8): footprint only. No active connection.
- [ ] RESET# (pin 3): 10kΩ pull-up to 3.3V.
- [ ] UARTRX (pin 4): unconnected.
- [ ] UARTTX (pin 5): unconnected.

**Jumpers:**
- [ ] JP1 pin 1: USB3-A VBUS. Pin 2: LDO input. Pin 3: micro-B VBUS.
- [ ] JP2 (pair): pin 1: USB3-A D+/D-. Pin 2: MCP2221A D+/D-. Pin 3: micro-B D+/D-.
- [ ] Both JP2 headers (D+ and D-) are always shorted in the same position.

**LEDs:**
- [ ] PWR LED: anode to 3.3V via 1kΩ, cathode to GND.
- [ ] LOS LED: anode to MCP2221A GP1 net (after 330Ω series from GP1 side), cathode to GND. Confirm polarity — LED must be OFF when RX_LOS is LOW (optical signal present).
- [ ] Spare LED footprint: 330Ω series to GP2. DNP.

**SFP+ cage ignored pins:**
- [ ] TX_FAULT (pin 2): unconnected.
- [ ] MOD_ABS (pin 6): footprint with 10kΩ pull-up to 3.3V, unconnected or to GP2/GP3 if desired.
- [ ] RS0 (pin 7), RS1 (pin 9): unconnected.

---
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

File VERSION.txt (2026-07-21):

usb3_fiber  —  USB3 SuperSpeed over an optical fiber link (DS100BR111 redriver + 10GbE SR SFP+)

Version:  development snapshot

This file names the version of the SOURCE PROJECT in this folder, so a copy
passed around as a .zip is never anonymous. The working tree is always a
development snapshot — released fabrication packages carry their exact version
on this line instead (stamped at build time by scripts/build_release.sh).

The authoritative, fabricated revisions — each stamped with its commit hash on
the bottom silkscreen and in every exported PDF — are published here:

    https://github.com/ringof/usb3-fiber/releases
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

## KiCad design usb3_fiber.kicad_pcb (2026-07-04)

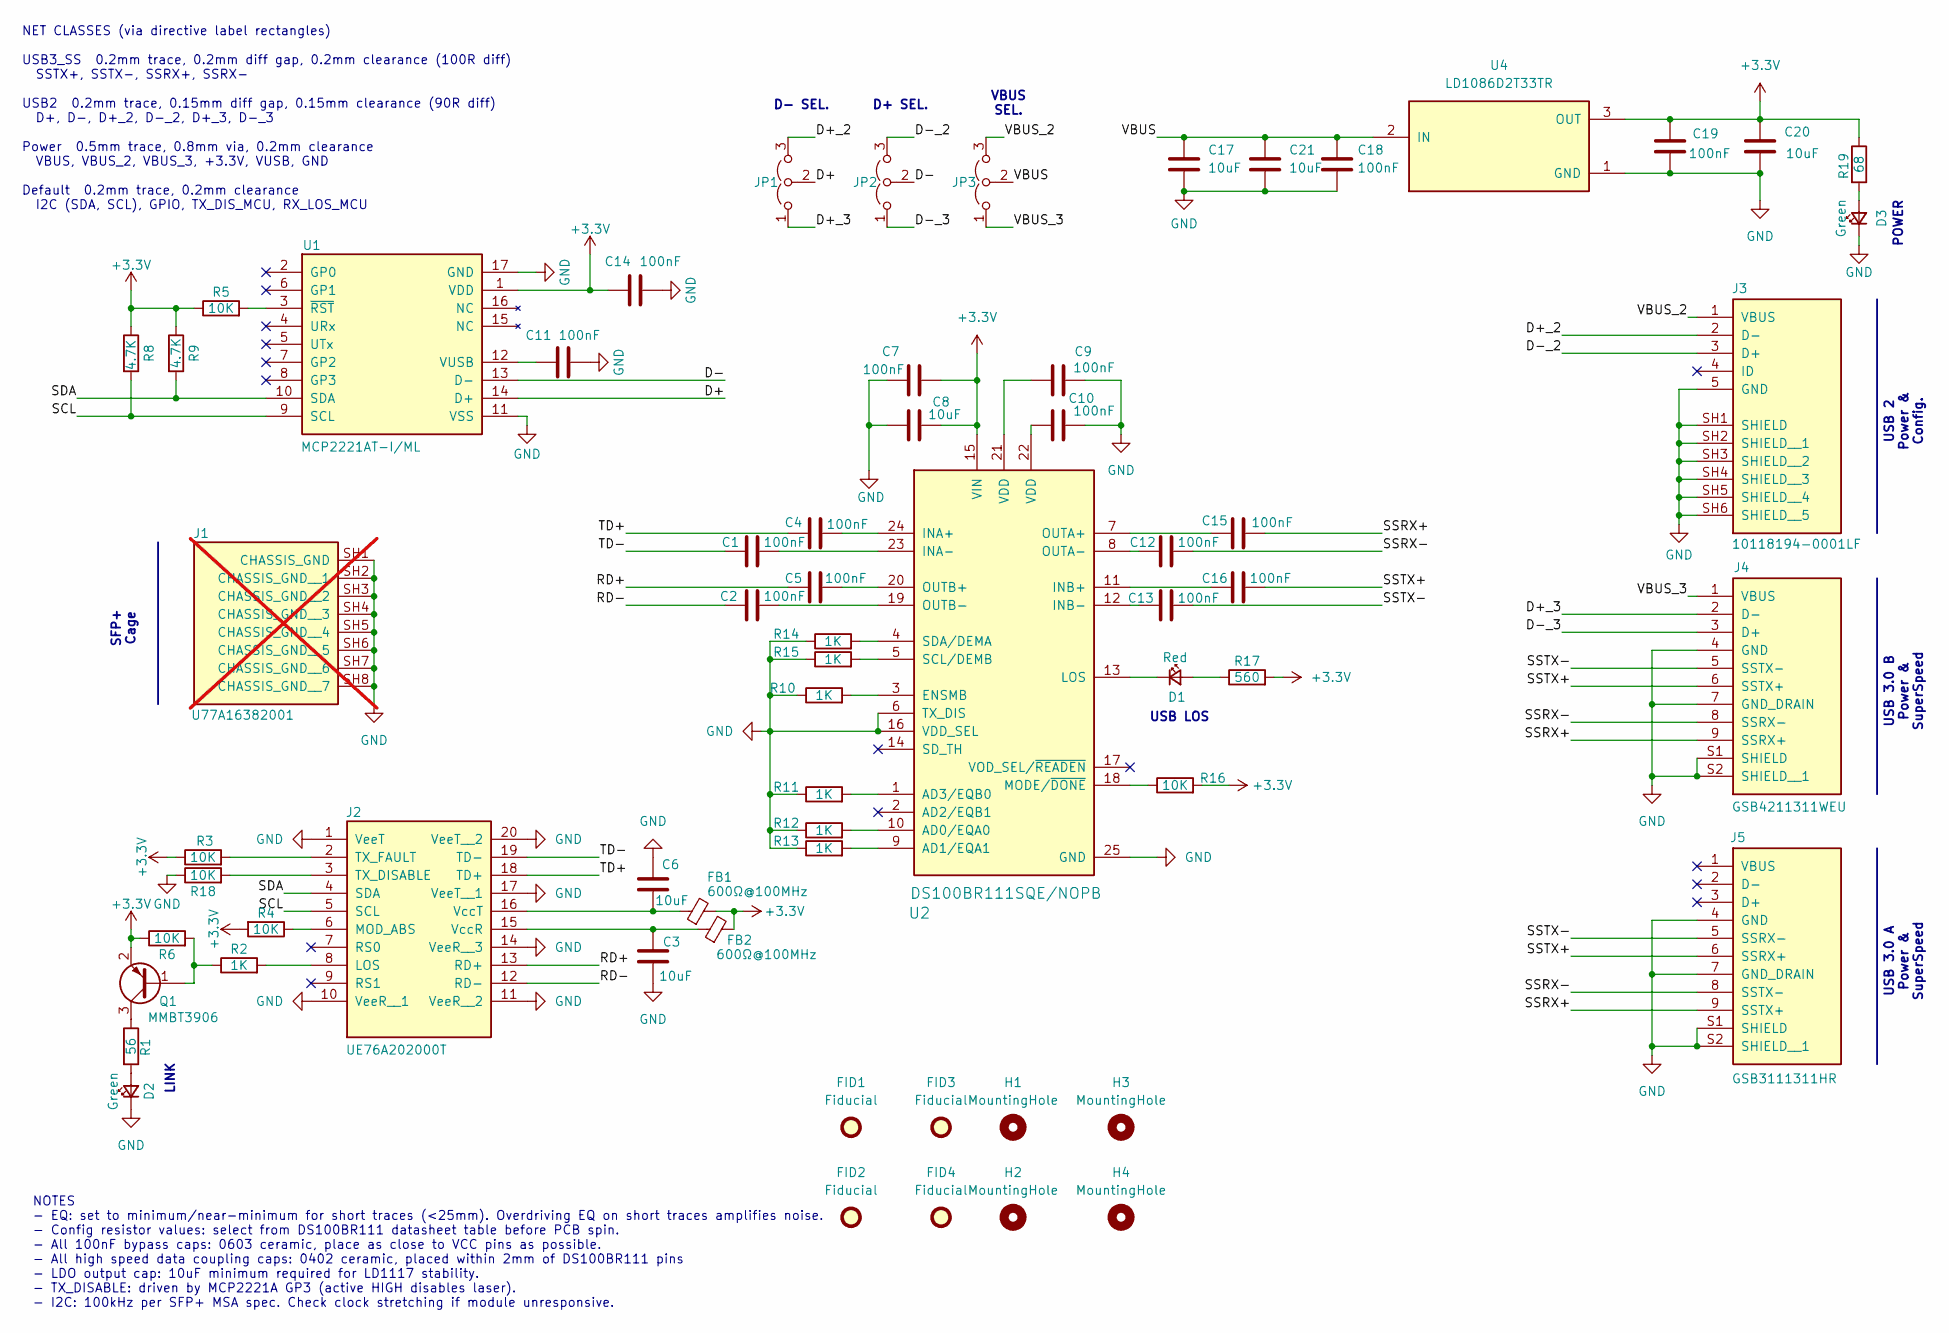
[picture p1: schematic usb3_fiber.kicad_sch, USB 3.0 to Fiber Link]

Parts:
C1, C2, C4, C5, C12, C13, C15, C16: 100nF; C_0402_1005Metric; Voltage 10V; Tolerance ±10%; Manufacturer Part Number CC0402KRX5R6BB104
C3, C6, C8, C17, C20, C21: 10uF; C_0805_2012Metric; Voltage 16V; Tolerance ±10%; Manufacturer Part Number CC0805KKX7R7BB106
C7, C9, C10, C14, C19: 100nF; C_0603_1608Metric; Voltage 10V; Tolerance ±10%; Manufacturer Part Number CC0603KRX7R6BB104
C11, C18: 100nF; C_0603_1608Metric; Voltage 16V; Tolerance ±10%; Manufacturer Part Number CC0603KRX7R7BB104
D1: Red; LED_0603_1608Metric; Manufacturer Part Number LTST-C190EKT
D2, D3: Green; LED_0603_1608Metric; Manufacturer Part Number LTST-C190GKT
FB1, FB2: 600Ω@100MHz; L_0603_1608Metric; Manufacturer Part Number BLM18KG601SN1D
FID1, FID2, FID3, FID4: Fiducial; Fiducial_1mm_Mask2mm
H1, H2, H3, H4: MountingHole; MountingHole_2.7mm_M2.5
J1: U77A16382001; AMPHENOL_U77A16382001; PARTREV B; not fitted
J2: UE76A202000T; AMPHENOL_UE76A202000T; PARTREV G
J3: 10118194-0001LF; AMPHENOL_10118194-0001LF; PARTREV D
J4: GSB4211311WEU; AMPHENOL_GSB4211311WEU; PARTREV B
J5: GSB3111311HR; AMPHENOL_GSB3111311HR
JP1, JP2, JP3: Jumper_3_Open; SolderJumper-3_P1.3mm_Open_Pad1.0x1.5mm
Q1: MMBT3906; SOT-23
R1: 56; R_0603_1608Metric; Tolerance ±1%; Manufacturer Part Number RC0603FR-0756RL
R2, R10, R11, R12, R13, R14, R15: 1K; R_0603_1608Metric; Tolerance ±1%; Manufacturer Part Number RC0603FR-071KL
R3, R4, R5, R6, R16, R18: 10K; R_0603_1608Metric; Tolerance ±1%; Manufacturer Part Number RC0603FR-0710KL
R8, R9: 4.7K; R_0603_1608Metric; Tolerance ±1%; Manufacturer Part Number RC0603FR-074K7L
R17: 560; R_0603_1608Metric; Tolerance ±1%; Manufacturer Part Number RC0603FR-07560RL
R19: 68; R_0603_1608Metric; Tolerance ±1%; Manufacturer Part Number RC0603FR-0768RL
U1: MCP2221AT-I/ML; QFN16_ML_MCH; Manufacturer Part Number MCP2221AT-I/ML
U2: DS100BR111SQE/NOPB; RTW24_2P6X2P6_TEX; Manufacturer Part Number DS100BR111SQE/NOPB
U4: LD1086D2T33TR; D2PAK_STM

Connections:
+3.3V: C7.2, C8.2, C14.1, C19.1, C20.1, FB1.2, FB2.2, Q1.2 (E), R3.1, R4.2, R5.1, R6.1, R8.1, R9.1, R16.2, R17.2, R19.1, U1.1 (VDD), U2.15 (VIN), U4.3 (OUT)
/D+: JP1.2 (C), U1.14 (D+)
/D+_2: J3.2 (D-), JP1.3 (B)
/D+_3: J4.2 (D-), JP1.1 (A)
/D-: JP2.2 (C), U1.13 (D-)
/D-_2: J3.3 (D+), JP2.3 (B)
/D-_3: J4.3 (D+), JP2.1 (A)
/RD+: C5.1, J2.13 (RD+)
/RD-: C2.1, J2.12 (RD-)
/SCL: J2.5 (SCL), R8.2, U1.9 (SCL)
/SDA: J2.4 (SDA), R9.2, U1.10 (SDA)
/SSRX+: C15.2, J4.9 (SSRX+), J5.9 (SSTX+)
/SSRX-: C12.2, J4.8 (SSRX-), J5.8 (SSTX-)
/SSTX+: C16.2, J4.6 (SSTX+), J5.6 (SSRX+)
/SSTX-: C13.2, J4.5 (SSTX-), J5.5 (SSRX-)
/TD+: C4.1, J2.18 (TD+)
/TD-: C1.1, J2.19 (TD-)
/VBUS: C17.1, C18.1, C21.1, JP3.2 (C), U4.2 (IN)
/VBUS_2: J3.1 (VBUS), JP3.3 (B)
/VBUS_3: J4.1 (VBUS), JP3.1 (A)
GND: C3.1, C6.1, C7.1, C8.1, C9.2, C10.2, C11.2, C14.2, C17.2, C18.2, C19.2, C20.2, C21.2, D2.1 (K), D3.1 (K), J1.SH1 (CHASSIS_GND), J1.SH2 (CHASSIS_GND__1), J1.SH3 (CHASSIS_GND__2), J1.SH4 (CHASSIS_GND__3), J1.SH5 (CHASSIS_GND__4), J1.SH6 (CHASSIS_GND__5), J1.SH7 (CHASSIS_GND__6), J1.SH8 (CHASSIS_GND__7), J2.1 (VeeT), J2.10 (VeeR__1), J2.11 (VeeR__2), J2.14 (VeeR__3), J2.17 (VeeT__1), J2.20 (VeeT__2), J3.5 (GND), J3.SH1 (SHIELD), J3.SH2 (SHIELD__1), J3.SH3 (SHIELD__2), J3.SH4 (SHIELD__3), J3.SH5 (SHIELD__4), J3.SH6 (SHIELD__5), J4.4 (GND), J4.7 (GND_DRAIN), J4.S1 (SHIELD), J4.S2 (SHIELD__1), J5.4 (GND), J5.7 (GND_DRAIN), J5.S1 (SHIELD), J5.S2 (SHIELD__1), R10.1, R11.1, R12.1, R13.1, R14.1, R15.1, R18.1, U1.11 (VSS), U1.17 (GND), U2.6 (TX_DIS), U2.16 (VDD_SEL), U2.25 (GND), U4.1 (GND)
unnamed: C9.1, U2.21 (VDD)
unnamed: C10.1, U2.22 (VDD)
unnamed: D1.2 (A), R17.1
unnamed: D1.1 (K), U2.13 (LOS)
unnamed: D2.2 (A), R1.2
unnamed: D3.2 (A), R19.2
unnamed: J2.8 (LOS), R2.2
unnamed: J2.6 (MOD_ABS), R4.1
unnamed: J2.3 (TX_DISABLE), R18.2
unnamed: J2.2 (TX_FAULT), R3.2
unnamed: C3.2, FB2.1, J2.15 (VccR)
unnamed: C6.2, FB1.1, J2.16 (VccT)
unnamed: Q1.1 (B), R2.1, R6.2
unnamed: Q1.3 (C), R1.1
unnamed: C11.1, U1.12 (VUSB)
unnamed: R5.2, U1.3 (~RST)
unnamed: R12.2, U2.10 (AD0/EQA0)
unnamed: R13.2, U2.9 (AD1/EQA1)
unnamed: R11.2, U2.1 (AD3/EQB0)
unnamed: R10.2, U2.3 (ENSMB)
unnamed: C4.2, U2.24 (INA+)
unnamed: C1.2, U2.23 (INA-)
unnamed: C16.1, U2.11 (INB+)
unnamed: C13.1, U2.12 (INB-)
unnamed: R16.1, U2.18 (MODE/~DONE)
unnamed: C15.1, U2.7 (OUTA+)
unnamed: C12.1, U2.8 (OUTA-)
unnamed: C5.2, U2.20 (OUTB+)
unnamed: C2.2, U2.19 (OUTB-)
unnamed: R15.2, U2.5 (SCL/DEMB)
unnamed: R14.2, U2.4 (SDA/DEMA)

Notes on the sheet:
NOTES - EQ: set to minimum/near-minimum for short traces (<25mm). Overdriving EQ on short traces amplifies noise. - Config resistor values: select from DS100BR111 datasheet table before PCB spin. - All 100nF bypass caps: 0603 ceramic, place as close to VCC pins as possible. - All high speed data co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
NET CLASSES (via directive label rectangles) USB3_SS 0.2mm trace, 0.2mm diff gap, 0.2mm clearance (100R diff) SSTX+, SSTX-, SSRX+, SSRX- USB2 0.2mm trace, 0.15mm diff gap, 0.15mm clearance (90R diff) D+, D-, D+_2, D-_2, D+_3, D-_3 Power 0.5mm trace, 0.8mm via, 0.2mm clearance VBUS, VBUS_2, VBUS_3, 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
USB 2 Power & Config.
SFP+ Cage
D- SEL.
POWER
VBUS SEL.
USB 3.0 A Power & SuperSpeed
USB LOS
D+ SEL.
USB 3.0 B Power & SuperSpeed
LINK

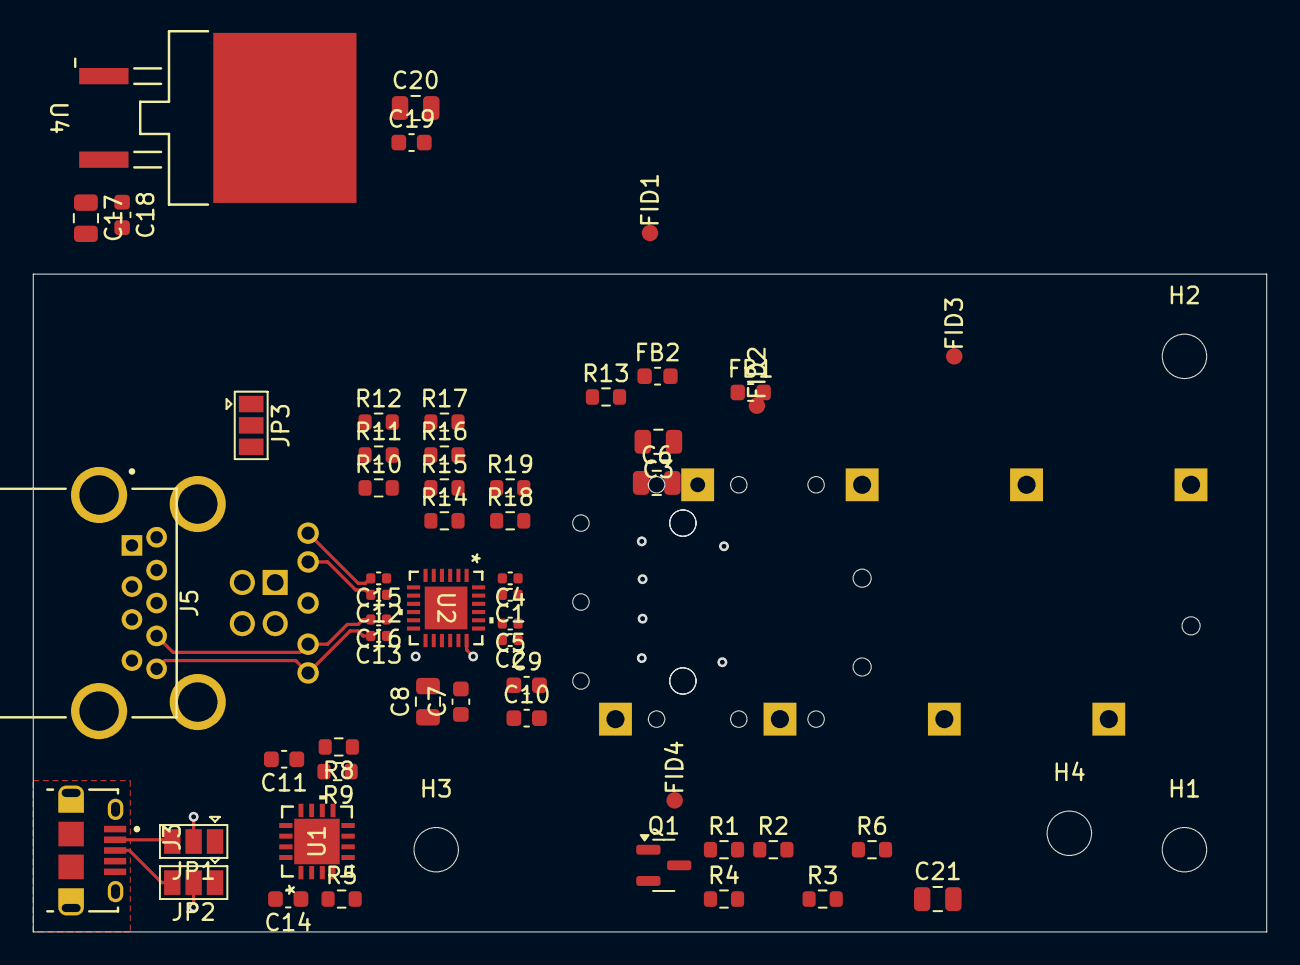
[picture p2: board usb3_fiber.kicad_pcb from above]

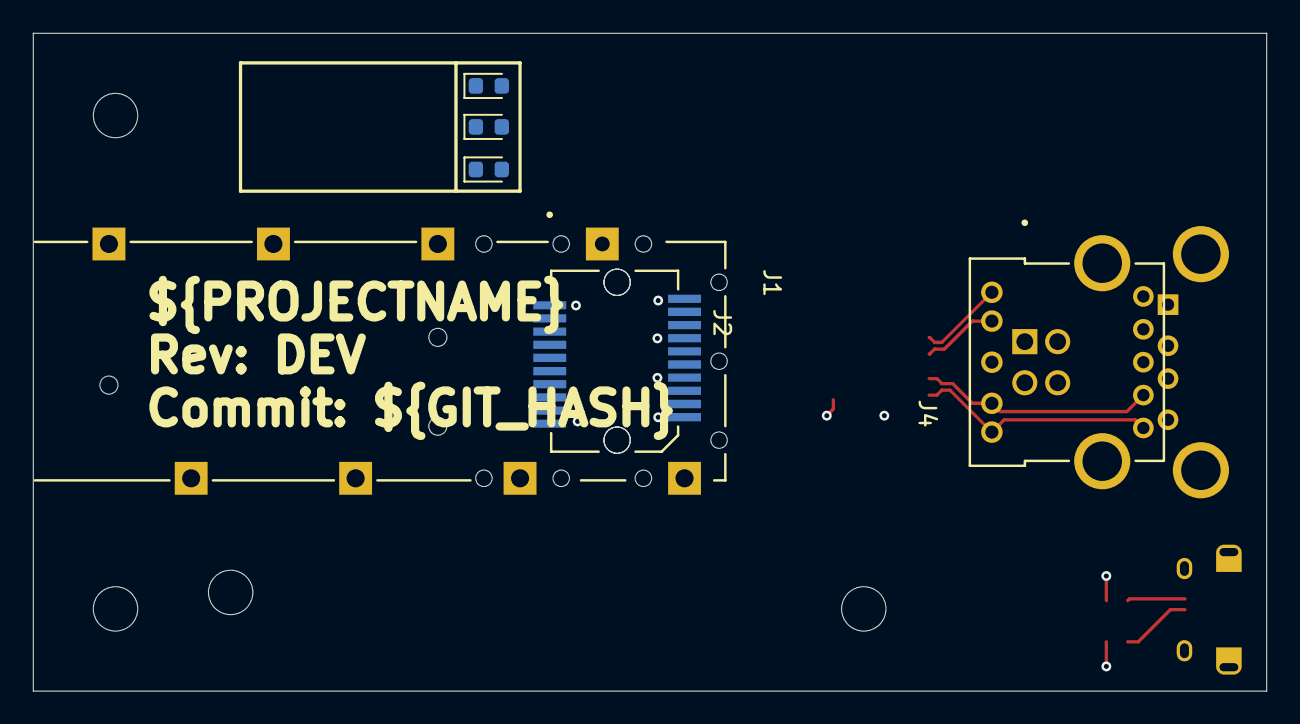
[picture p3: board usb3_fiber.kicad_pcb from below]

Board: 4 copper layers, 75.0 x 40.0 mm, 64 parts (6 on the bottom side), 52 nets.

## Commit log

2026-07-03 Initial commit: USB3-to-fiber KiCad 8.0 project
    Schematic, PCB layout, custom symbol/footprint libraries,
    3D STEP models, datasheets, and fab specification.
    [usb3_fiber.kicad_pcb, usb3_fiber.kicad_sch]
2026-07-03 update to KiCAD 10
    [usb3_fiber.kicad_pcb, usb3_fiber.kicad_sch]
2026-07-03 docs: add KiCad repo migration plan (CI/release/provenance)
    Ports the repository-infrastructure pattern from ringof/taprx888 to this
    project: CI fabrication pipeline, GIT_HASH provenance, ERC/DRC audit,
    README/LICENSE, and tagged releases. Excludes the AI schematic-review
    docs per scope. Documents current-state gap analysis and a phased plan.
    Claude-Session: https://claude.ai/code/session_012vRW6hhKX7UfnTmWpMyfnj
2026-07-03 docs: incorporate agreed requirements into migration plan
    Fold in the seven decisions: flat repo layout, protected main + dev-*
    branches, two-tier CI (dev checks + drawings / main full fab package),
    alpha revision injected at build time with GitHub Releases as source of
    truth, KLC library audit (warning-level), JLCPCB standard 4-layer rule
    baseline, 3D-model completeness gate on fitted parts, and BOM check.
    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
2026-07-03 Add tailored CLAUDE.md working agreement
    Port the portable conventions from ringof/rx888-firmware's CLAUDE.md and
    adapt them to this KiCad hardware repo: planning-first, commit/push only
    with approval, branch discipline (main protected, dev-* work, work != a
    branch), evidence-before-claims, and a hardware change-documentation
    block. Add repo specifics: layout, KiCad 8 tooling, JLCPCB rule
    baseline, the dev/main CI gate-vs-warning matrix, and build-time
    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
2026-07-03 Make KiCad 10.0 the immediate baseline (migrate up front)
    Replace the earlier 'pin to KiCad 8, defer the upgrade' stance: KiCad
    10.0 (latest stable 10.0.4) is the project baseline, and migrating the
    files to the v10 format is the first task (Phase 0), kept in its own
    commit. Pin CI to KiCad 10.0.x. Restore the direct 'kicad-cli sch export
    bom' command (available in KiCad 9+). Drop the 8->9 deferral open item.
    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
2026-07-03 Flatten KiCad project to repo root
    Move the design, libraries, datasheets, docs, and lib tables out of the
    usb3_fiber/ subdirectory up to the repo root (requirement #1). All
    internal paths use ${KIPRJMOD}/env vars, so the lib tables and 3D-model
    links resolve unchanged.
    Also remove usb3_fiber/.history — an orphan gitlink (submodule reference
    with no .gitmodules, empty on disk) accidentally committed during the
    KiCad 10 upgrade — from tracking, and add .history/ to .gitignore.
    Update CLAUDE.md and the migration plan to reflect the flat layout.
    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
    [usb3_fiber.kicad_pcb, usb3_fiber.kicad_sch]
2026-07-03 Add root README
    Project overview, architecture diagram, the central hypothesis, repo
    layout, KiCad 10 build commands, JLCPCB fab summary, a Releases/downloads
    section (provenance-stamped packages, forthcoming), status, and license.
    Completes the Phase 1 repo-hygiene items.
    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
2026-07-03 ci: dev-checks workflow (ERC/DRC/BOM + schematic/assembly drawings) (#4)
    * Add dev-checks CI workflow (ERC/DRC/BOM + drawings)
    Phase 3 dev CI: run ERC, DRC (honoring usb3_fiber.kicad_dru), and a BOM
    completeness check in a KiCad 10 container, and generate the schematic
    PDF + top/bottom assembly drawings as artifacts. Triggers on dev-*
    pushes and PRs into main.
    Gating is governed by an ENFORCE toggle, default false for bring-up:
    checks run and upload reports but do not fail the job, so the first run
    captures the ERC/DRC/BOM baseline as artifacts. Flip ENFORCE=true (and
    add these as required status checks in the main ruleset) once the
    baseline is triaged.
    BOM check (scripts/bom_check.py) ve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
2026-07-03 ci: main-release workflow + build-time revision/GIT_HASH provenance (#5)
    * Add main-release CI + build-time revision/GIT_HASH provenance
    Phase 4 (folds in Phase 2 provenance):
    - Define ${REVISION}/${GIT_HASH} project text variables and reference
    them in the schematic + PCB title blocks (rev field + git-hash
    comment). Defaults are placeholders; CI overwrites them at build time.
    - scripts/build_release.sh: inject REVISION/GIT_HASH into the project
    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
    [usb3_fiber.kicad_pcb, usb3_fiber.kicad_sch]
2026-07-03 ci: release strategy — conditional uprev, design-commit provenance, stable assets + download links (#16)
    * ci: bump download-artifact to @v8 (Node 24)
    actions/download-artifact@v6 still targets Node 20 (verified via its
    action.yml runs.using) while checkout@v6 and upload-artifact@v6 are
    Node 24. Bump download-artifact to @v8 to clear the remaining Node 20
    deprecation annotation on the release job.
    * release: publish stable-named assets + README quick download links
    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
2026-07-03 gitignore .claude/; self-clean stale release assets (#19)
    - Add .claude/ to .gitignore (local agent/session state; was only
    ignored by the environment's local exclude, not the committed file).
    - main-release: after publishing, delete any release assets not in the
    stable set (schematic.pdf / gerbers.zip / fabrication.zip) so a
    renamed or legacy asset can't linger on the release.
    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
2026-07-03 drc: re-enable courtyard checks (#15) (#20)
    Turn the disabled courtyard DRC rules back on in the board design
    settings, per the JLCPCB baseline (requirement #7 / taprx888 pattern):
    - pth_inside_courtyard: ignore -> error
    - npth_inside_courtyard: ignore -> error
    - missing_courtyard: ignore -> warning
    pth/npth-inside-courtyard are real mechanical/clearance violations
    (error); a missing courtyard is a library-quality issue (warning,
    overlaps the KLC audit). Non-gating for now (dev CI ENFORCE=false) — this
    surfaces the items in the DRC baseline until ENFORCE is flipped.
    Claude-Session: https://claude.ai/code/session_012vRW6hhKX7UfnTmWpMyfnj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
2026-07-03 flow: two-tier feature -> dev -> main (GitFlow) (#22)
    Introduce a permanent 'dev' integration branch. Feature dev-* branches
    merge (squash) into dev; dev merges (squash) into main only when cutting
    a release.
    - dev-checks now runs on PRs into BOTH dev and main (same ERC/DRC/BOM +
    drawings gate feature->dev and dev->main), plus dev-* pushes.
    - main-release is unchanged: a merge to main still builds and, if the
    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
2026-07-03 titleblock: custom worksheet + proper provenance variables (#23)
    Add usb3_fiber.kicad_wks (custom drawing sheet) and point the schematic
    and board page_layout_descr_file at it. The block now shows Title, Rev,
    Date, Page, Designer, OSH Licence, Repo, and Commit via proper fields.
    Rework provenance to kill the name clash (project var vs
    KiCad built-in):
    - Project text variables: add DESIGNER, LICENSE, REPO; keep GIT_HASH;
    REMOVE REVISION.
    - Title-block rev field is now a literal placeholder ('DEV'); CI writes
    it at build time via the built-in path.
    - build_release.sh injects REVISION into the sch/pcb title-block rev
    field (regex, one occurrence each) and GIT_HASH as a text variable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
    [usb3_fiber.kicad_pcb, usb3_fiber.kicad_sch]
2026-07-03 kibot: turnkey pipeline checkpoint — config, provenance script, LCSC-required BOM gate (#24)
    Add the reviewable pieces of the KiBot migration ahead of the workflow
    rewiring:
    - usb3_fiber.kibot.yaml: fab-agnostic base + JLCPCB turnkey profile.
    ERC/DRC preflights, docs (schematic PDF, assembly drawings, iBOM),
    fab (STEP, 3D renders), and JLCPCB group (gerbers, drill,
    rotation-corrected CPL via the 'rotated' variant, LCSC-keyed BOM).
    Adapted to this design: LCSC field (not LCSC#) and 4-layer stackup.
    - scripts/inject_provenance.py: extract the title-block rev + GIT_HASH
    injection out of build_release.sh into a standalone, locally-testable
    step. KiBot only generates; provenance i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
2026-07-03 kibot: wire dev-checks + main-release to KiBot (workflow surgery) (#25)
    Complete the KiBot migration — the workflow rewiring held back from the
    config checkpoint (#24). Injection and GitFlow are preserved intact.
    - main-release: build via KiBot. build_release.sh now runs
    inject_provenance.py (title-block rev + GIT_HASH) FIRST, then KiBot
    generates the full turnkey package from usb3_fiber.kibot.yaml with
    preflights skipped (gating already happened on the PR into main). 3D
    renders are best-effort so a raytrace hiccup can't sink a release. The
    release job's packaging paths follow KiBot's output dirs
    (docs/usb3_fiber-schematic.pdf, JLCPCB/gerbers/). Container ->
    ghcr.io/inti-cmn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
2026-07-03 kibot: call kibot directly instead of xvfb-run (no xauth in image) (#27)
    The dry-run build failed at 'xvfb-run: error: xauth command not found' —
    the kicad10_auto image ships Xvfb but not xauth, so xvfb-run can't
    launch. KiBot manages its own virtual display via xvfbwrapper for the
    outputs that need one (render_3d, pcb_print), which is how the official
    KiBot action runs it. Drop the xvfb-run wrapper in both scripts and call
    kibot directly.
    The failed run confirmed everything up to this point works: prepare
    computed rev C / githash 49d63a4, inject_provenance.py stamped the title
    blocks, and the release job was correctly skipped under dry_run.
    Claude-Session: https://claude.ai/code/sessio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
2026-07-04 pcb: dedicated fab worksheet + multi-page assembly documentation set (#28)
    * pcb: dedicated fab worksheet + multi-page assembly doc set
    Give the PCB its own page-layout sheet, distinct from the schematic, and
    turn the assembly output into a proper documentation set.
    - usb3_fiber-fab.kicad_wks: new PCB worksheet, seeded from the schematic
    frame's proven collision-safe title block (${REVISION} field +
    ${GIT_HASH}/${LICENSE}/${DESIGNER}/${REPO} vars). Starting point to
    rearrange in the Page Layout Editor with fab-specific zones.
    - usb3_fiber.kicad_pro: board (pcbnew) page_layout_descr_file -> the fab
    sheet; the schematic section keeps usb3_fiber.kicad_wks. The two sheets
    are now ind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
    [usb3_fiber.kicad_pcb]
2026-07-21 Back-port from taprx888: scope release triggers + add AI_REVIEW.md (#38, #42) (#48) (#49)
    * ci: scope release triggers to explicit root design files (#38)
    main-release.yml decided whether to cut a new revision by diffing a
    DESIGN pathspec list built from bare globs (*.kicad_sch, *.kicad_pcb,
    ...). A bare glob is a git pathspec that matches at ANY depth, so once a
    sibling KiCad project lands under mechanical/ (enclosure / end plates),
    an edit to a panel or case board would false-trigger a board release.
    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
2026-07-21 Reset versioning to semver (0.x pre-releases → 1.0 → 1.x …), TAPRx888-style (#50)
    * ci: add pure, unit-tested next_version.sh version policy (#39)
    Extract the release-numbering policy into a single pure, stdin-driven
    script shared by both release lanes, with offline unit tests that prove
    the full lifecycle (0.1 → 1.0 → 1.x → 2.0 → 2.x) without cutting real
    releases.
    Semver policy (see docs/RELEASE_STRATEGY.md):
    - main: next whole major .0 (first ever → 1.0); every production release
    is a major.
    - dev: minor++ within the current major line, whose major follows the
    latest main release (0 pre-1.0); first pre-release seeds at 0.1.
    Ported from ringof/taprx888 with the seed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
2026-07-21 docs: README revision info matches the semver scheme, not a hardcoded letter (#31) (#53)
    The Status line hardcoded "Rev A" and the Downloads section described an alpha
    "Rev A → B → C" scheme — both stale (doubly so after the semver reset). Drop the
    hardcoded revision (point at Releases, since it's stamped into the board, not the
    README) and describe the actual vMAJOR.MINOR scheme (v0.x pre-releases on dev,
    production vX.0 on main). Also notes the /releases/latest/download links resolve
    to the newest *production* release, so pre-1.0 downloads come from the specific
    pre-release page.
    Closes #31
    Claude-Session: https://claude.ai/code/session_01VXxQULreR365VhJ483EUb6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
2026-07-21 mechanical: scaffold the sibling-project convention (#41) (#54)
    Add mechanical/README.md fixing the convention for enclosure + end-plate
    design, back-ported from ringof/taprx888:mechanical/README.md and adapted to
    usb3-fiber's symmetric board and connectors (USB3-A J3/J4, SFP+ cage J1, USB
    micro-B mgmt):
    - end plates are each their own self-contained KiCad project; the root board is
    untouched, so a connector move + its cutout land as one atomic commit;
    - mechanical changes do NOT cut a board release (the release lanes are scoped to
    explicit root board files, done in #38 — mechanical/ can't false-trigger);
    - the board STEP is the EE<->ME interface (already exported by build_release.sh;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
